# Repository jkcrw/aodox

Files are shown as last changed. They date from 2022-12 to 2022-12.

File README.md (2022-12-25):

# AODox
Fully custom mechanical keyboard optimized for speed/ergonomics. Supports standard Qwerty and Qwerty-like key layouts as well as [Sparrowhawk steno](https://github.com/jxcrw/sphk). Powered by [QMK Firmware](https://github.com/qmk/qmk_firmware).

More documentation coming when time allows.

<p align="center">
  
</p>

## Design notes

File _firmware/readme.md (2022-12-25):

# AODox

AODox

A short description of the keyboard/project

* Keyboard Maintainer: [jxcrw](https://github.com/yourusername)
* Hardware Supported: The PCBs, controllers supported
* Hardware Availability: Links to where you can find this hardware

Make example for this keyboard (after setting up your build environment):

    make aodox:default

See the [build environment setup](https://docs.qmk.fm/#/getting_started_build_tools) and the [make instructions](https://docs.qmk.fm/#/getting_started_make_guide) for more information. Brand new to QMK? Start with our [Complete Newbs Guide](https://docs.qmk.fm/#/newbs).

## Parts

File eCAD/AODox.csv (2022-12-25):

Reference | Value | Footprint | Datasheet
U1 | ATMEGA32U4 | Package_QFP:TQFP-44_10x10mm_P0.8mm
J2 | USB C Port | Connector_USB:USB_C_Receptacle_GCT_USB4085 | https://www.usb.org/sites/default/files/documents/usb_type-c.zip
C7 | 22p | Capacitor_SMD:C_0805_2012Metric_Pad1.15x1.40mm_HandSolder | ~
C6 | 22p | Capacitor_SMD:C_0805_2012Metric_Pad1.15x1.40mm_HandSolder | ~
C1 | 0.1u | Capacitor_SMD:C_0805_2012Metric_Pad1.15x1.40mm_HandSolder | ~
C2 | 0.1u | Capacitor_SMD:C_0805_2012Metric_Pad1.15x1.40mm_HandSolder | ~
C3 | 0.1u | Capacitor_SMD:C_0805_2012Metric_Pad1.15x1.40mm_HandSolder | ~
C4 | 0.1u | Capacitor_SMD:C_0805_2012Metric_Pad1.15x1.40mm_HandSolder | ~
C5 | 4.7u | Capacitor_SMD:C_0805_2012Metric_Pad1.15x1.40mm_HandSolder | ~
SW1 | SW_Push | Button_Switch_SMD:SW_SPST_CK_KXT3 | ~
R1 | 10k | Resistor_SMD:R_0805_2012Metric_Pad1.15x1.40mm_HandSolder | ~
R4 | 10k | Resistor_SMD:R_0805_2012Metric_Pad1.15x1.40mm_HandSolder | ~
R5 | 5.1k | Resistor_SMD:R_0805_2012Metric_Pad1.15x1.40mm_HandSolder | ~
R6 | 5.1k | Resistor_SMD:R_0805_2012Metric_Pad1.15x1.40mm_HandSolder | ~
R2 | 22 | Resistor_SMD:R_0805_2012Metric_Pad1.15x1.40mm_HandSolder | ~
R3 | 22 | Resistor_SMD:R_0805_2012Metric_Pad1.15x1.40mm_HandSolder | ~
C8 | 1u | Capacitor_SMD:C_0805_2012Metric_Pad1.15x1.40mm_HandSolder | ~
J1 | MCU Prog | Connector_PinHeader_2.54mm:PinHeader_1x06_P2.54mm_Vertical | ~
Y1 | XTAL_18p | Crystal:Crystal_SMD_SeikoEpson_FA238-4Pin_3.2x2.5mm_HandSoldering | ~
K0:1 | KEYSW | keyboard_parts_AO:Kailh_socket
D0:1 | D_Small_ALT | Diode_SMD:D_SOD-323_HandSoldering | ~
K1:1 | KEYSW | keyboard_parts_AO:Kailh_socket
D1:1 | D_Small_ALT | Diode_SMD:D_SOD-323_HandSoldering | ~
K2:1 | KEYSW | keyboard_parts_AO:Kailh_socket
D2:1 | D_Small_ALT | Diode_SMD:D_SOD-323_HandSoldering | ~
K3:1 | KEYSW | keyboard_parts_AO:Kailh_socket
D3:1 | D_Small_ALT | Diode_SMD:D_SOD-323_HandSoldering | ~
K4:1 | KEYSW | keyboard_parts_AO:Kailh_socket
D4:1 | D_Small_ALT | Diode_SMD:D_SOD-323_HandSoldering | ~
K0:2 | KEYSW | keyboard_parts_AO:Kailh_socket
D0:2 | D_Small_ALT | Diode_SMD:D_SOD-323_HandSoldering | ~
K1:2 | KEYSW | keyboard_parts_AO:Kailh_socket
D1:2 | D_Small_ALT | Diode_SMD:D_SOD-323_HandSoldering | ~
K2:2 | KEYSW | keyboard_parts_AO:Kailh_socket
D2:2 | D_Small_ALT | Diode_SMD:D_SOD-323_HandSoldering | ~
K3:2 | KEYSW | keyboard_parts_AO:Kailh_socket
D3:2 | D_Small_ALT | Diode_SMD:D_SOD-323_HandSoldering | ~
K4:2 | KEYSW | keyboard_parts_AO:Kailh_socket
D4:2 | D_Small_ALT | Diode_SMD:D_SOD-323_HandSoldering | ~
K0:3 | KEYSW | keyboard_parts_AO:Kailh_socket
D0:3 | D_Small_ALT | Diode_SMD:D_SOD-323_HandSoldering | ~
K1:3 | KEYSW | keyboard_parts_AO:Kailh_socket
D1:3 | D_Small_ALT | Diode_SMD:D_SOD-323_HandSoldering | ~
K2:3 | KEYSW | keyboard_parts_AO:Kailh_socket
D2:3 | D_Small_ALT | Diode_SMD:D_SOD-323_HandSoldering | ~
K3:3 | KEYSW | keyboard_parts_AO:Kailh_socket
D3:3 | D_Small_ALT | Diode_SMD:D_SOD-323_HandSoldering | ~
K4:3 | KEYSW | keyboard_parts_AO:Kailh_socket
D4:3 | D_Small_ALT | Diode_SMD:D_SOD-323_HandSoldering | ~
K0:4 | KEYSW | keyboard_parts_AO:Kailh_socket
D0:4 | D_Small_ALT | Diode_SMD:D_SOD-323_HandSoldering | ~
K1:4 | KEYSW | keyboard_parts_AO:Kailh_socket
D1:4 | D_Small_ALT | Diode_SMD:D_SOD-323_HandSoldering | ~
K2:4 | KEYSW | keyboard_parts_AO:Kailh_socket
D2:4 | D_Small_ALT | Diode_SMD:D_SOD-323_HandSoldering | ~
K3:4 | KEYSW | keyboard_parts_AO:Kailh_socket
D3:4 | D_Small_ALT | Diode_SMD:D_SOD-323_HandSoldering | ~
K4:4 | KEYSW | keyboard_parts_AO:Kailh_socket
D4:4 | D_Small_ALT | Diode_SMD:D_SOD-323_HandSoldering | ~
K0:5 | KEYSW | keyboard_parts_AO:Kailh_socket
D0:5 | D_Small_ALT | Diode_SMD:D_SOD-323_HandSoldering | ~
K1:5 | KEYSW | keyboard_parts_AO:Kailh_socket
D1:5 | D_Small_ALT | Diode_SMD:D_SOD-323_HandSoldering | ~
K2:5 | KEYSW | keyboard_parts_AO:Kailh_socket
D2:5 | D_Small_ALT | Diode_SMD:D_SOD-323_HandSoldering | ~
K3:5 | KEYSW | keyboard_parts_AO:Kailh_socket
D3:5 | D_Small_ALT | Diode_SMD:D_SOD-323_HandSoldering | ~
K4:5 | KEYSW | keyboard_parts_AO:Kailh_socket
D4:5 | D_Small_ALT | Diode_SMD:D_SOD-323_HandSoldering | ~
K0:6 | KEYSW | keyboard_parts_AO:Kailh_socket
D0:6 | D_Small_ALT | Diode_SMD:D_SOD-323_HandSoldering | ~
K1:6 | KEYSW | keyboard_parts_AO:Kailh_socket
D1:6 | D_Small_ALT | Diode_SMD:D_SOD-323_HandSoldering | ~
K2:6 | KEYSW | keyboard_parts_AO:Kailh_socket
D2:6 | D_Small_ALT | Diode_SMD:D_SOD-323_HandSoldering | ~
K4:6 | KEYSW | keyboard_parts_AO:Kailh_socket
D4:6 | D_Small_ALT | Diode_SMD:D_SOD-323_HandSoldering | ~
K4:7 | KEYSW | keyboard_parts_AO:Kailh_socket
D4:7 | D_Small_ALT | Diode_SMD:D_SOD-323_HandSoldering | ~
K3:7 | KEYSW | keyboard_parts_AO:Kailh_socket
D3:7 | D_Small_ALT | Diode_SMD:D_SOD-323_HandSoldering | ~
D4:0 | D_Small_ALT | Diode_SMD:D_SOD-323_HandSoldering | ~
K4:0 | KEYSW | keyboard_parts_AO:Kailh_socket
D3:0 | D_Small_ALT | Diode_SMD:D_SOD-323_HandSoldering | ~
K3:0 | KEYSW | keyboard_parts_AO:Kailh_socket
D2:0 | D_Small_ALT | Diode_SMD:D_SOD-323_HandSoldering | ~
K2:0 | KEYSW | keyboard_parts_AO:Kailh_socket
D1:0 | D_Small_ALT | Diode_SMD:D_SOD-323_HandSoldering | ~
K1:0 | KEYSW | keyboard_parts_AO:Kailh_socket
D0:0 | D_Small_ALT | Diode_SMD:D_SOD-323_HandSoldering | ~
K0:0 | KEYSW | keyboard_parts_AO:Kailh_socket
K1:8 | KEYSW | keyboard_parts_AO:Kailh_socket
D1:8 | D_Small_ALT | Diode_SMD:D_SOD-323_HandSoldering | ~
K2:8 | KEYSW | keyboard_parts_AO:Kailh_socket
D2:8 | D_Small_ALT | Diode_SMD:D_SOD-323_HandSoldering | ~
K4:9 | KEYSW | keyboard_parts_AO:Kailh_socket
D4:9 | D_Small_ALT | Diode_SMD:D_SOD-323_HandSoldering | ~
K3:9 | KEYSW | keyboard_parts_AO:Kailh_socket
D3:9 | D_Small_ALT | Diode_SMD:D_SOD-323_HandSoldering | ~
K0:10 | KEYSW | keyboard_parts_AO:Kailh_socket
D0:10 | D_Small_ALT | Diode_SMD:D_SOD-323_HandSoldering | ~
K1:10 | KEYSW | keyboard_parts_AO:Kailh_socket
D1:10 | D_Small_ALT | Diode_SMD:D_SOD-323_HandSoldering | ~
K2:10 | KEYSW | keyboard_parts_AO:Kailh_socket
D2:10 | D_Small_ALT | Diode_SMD:D_SOD-323_HandSoldering | ~
K4:10 | KEYSW | keyboard_parts_AO:Kailh_socket
D4:10 | D_Small_ALT | Diode_SMD:D_SOD-323_HandSoldering | ~
K0:12 | KEYSW | keyboard_parts_AO:Kailh_socket
D0:12 | D_Small_ALT | Diode_SMD:D_SOD-323_HandSoldering | ~
K1:12 | KEYSW | keyboard_parts_AO:Kailh_socket
D1:12 | D_Small_ALT | Diode_SMD:D_SOD-323_HandSoldering | ~
K2:12 | KEYSW | keyboard_parts_AO:Kailh_socket
D2:12 | D_Small_ALT | Diode_SMD:D_SOD-323_HandSoldering | ~
K3:12 | KEYSW | keyboard_parts_AO:Kailh_socket
D3:12 | D_Small_ALT | Diode_SMD:D_SOD-323_HandSoldering | ~
K4:12 | KEYSW | keyboard_parts_AO:Kailh_socket
D4:12 | D_Small_ALT | Diode_SMD:D_SOD-323_HandSoldering | ~
K0:13 | KEYSW | keyboard_parts_AO:Kailh_socket
D0:13 | D_Small_ALT | Diode_SMD:D_SOD-323_HandSoldering | ~
K1:13 | KEYSW | keyboard_parts_AO:Kailh_socket
D1:13 | D_Small_ALT | Diode_SMD:D_SOD-323_HandSoldering | ~
K2:13 | KEYSW | keyboard_parts_AO:Kailh_socket
D2:13 | D_Small_ALT | Diode_SMD:D_SOD-323_HandSoldering | ~
K3:13 | KEYSW | keyboard_parts_AO:Kailh_socket
D3:13 | D_Small_ALT | Diode_SMD:D_SOD-323_HandSoldering | ~
K4:13 | KEYSW | keyboard_parts_AO:Kailh_socket
D4:13 | D_Small_ALT | Diode_SMD:D_SOD-323_HandSoldering | ~
K0:14 | KEYSW | keyboard_parts_AO:Kailh_socket
D0:14 | D_Small_ALT | Diode_SMD:D_SOD-323_HandSoldering | ~
K1:14 | KEYSW | keyboard_parts_AO:Kailh_socket
D1:14 | D_Small_ALT | Diode_SMD:D_SOD-323_HandSoldering | ~
K2:14 | KEYSW | keyboard_parts_AO:Kailh_socket
D2:14 | D_Small_ALT | Diode_SMD:D_SOD-323_HandSoldering | ~
K3:14 | KEYSW | keyboard_parts_AO:Kailh_socket
D3:14 | D_Small_ALT | Diode_SMD:D_SOD-323_HandSoldering | ~
K4:14 | KEYSW | keyboard_parts_AO:Kailh_socket
D4:14 | D_Small_ALT | Diode_SMD:D_SOD-323_HandSoldering | ~
K0:15 | KEYSW | keyboard_parts_AO:Kailh_socket
D0:15 | D_Small_ALT | Diode_SMD:D_SOD-323_HandSoldering | ~
K1:15 | KEYSW | keyboard_parts_AO:Kailh_socket
D1:15 | D_Small_ALT | Diode_SMD:D_SOD-323_HandSoldering | ~
K2:15 | KEYSW | keyboard_parts_AO:Kailh_socket
D2:15 | D_Small_ALT | Diode_SMD:D_SOD-323_HandSoldering | ~
K3:15 | KEYSW | keyboard_parts_AO:Kailh_socket
D3:15 | D_Small_ALT | Diode_SMD:D_SOD-323_HandSoldering | ~
K4:15 | KEYSW | keyboard_parts_AO:Kailh_socket
D4:15 | D_Small_ALT | Diode_SMD:D_SOD-323_HandSoldering | ~
K0:16 | KEYSW | keyboard_parts_AO:Kailh_socket
D0:16 | D_Small_ALT | Diode_SMD:D_SOD-323_HandSoldering | ~
K1:16 | KEYSW | keyboard_parts_AO:Kailh_socket
D1:16 | D_Small_ALT | Diode_SMD:D_SOD-323_HandSoldering | ~
K2:16 | KEYSW | keyboard_parts_AO:Kailh_socket
D2:16 | D_Small_ALT | Diode_SMD:D_SOD-323_HandSoldering | ~
K3:16 | KEYSW | keyboard_parts_AO:Kailh_socket
D3:16 | D_Small_ALT | Diode_SMD:D_SOD-323_HandSoldering | ~
K4:16 | KEYSW | keyboard_parts_AO:Kailh_socket
D4:16 | D_Small_ALT | Diode_SMD:D_SOD-323_HandSoldering | ~
D4:11 | D_Small_ALT | Diode_SMD:D_SOD-323_HandSoldering | ~
K4:11 | KEYSW | keyboard_parts_AO:Kailh_socket
D3:11 | D_Small_ALT | Diode_SMD:D_SOD-323_HandSoldering | ~
K3:11 | KEYSW | keyboard_parts_AO:Kailh_socket
D2:11 | D_Small_ALT | Diode_SMD:D_SOD-323_HandSoldering | ~
K2:11 | KEYSW | keyboard_parts_AO:Kailh_socket
D1:11 | D_Small_ALT | Diode_SMD:D_SOD-323_HandSoldering | ~
K1:11 | KEYSW | keyboard_parts_AO:Kailh_socket
D0:11 | D_Small_ALT | Diode_SMD:D_SOD-323_HandSoldering | ~
K0:11 | KEYSW | keyboard_parts_AO:Kailh_socket

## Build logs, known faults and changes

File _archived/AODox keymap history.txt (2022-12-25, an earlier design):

commit da2d01808503ddcafd8279fb72374b3331a3387b
Merge: 33126c9246 ae34dde677
Author: Jak Crow <jak@jxcrw.io>
Date:   Sat Dec 11 19:10:52 2021 -0800

    Merge branch 'master' of https://github.com/qmk/qmk_firmware

commit 33126c92460ebc105c9933ecef562ca10e2ec47d
Author: Jak Crow <jak@jxcrw.io>
Date:   Sat Dec 11 17:25:13 2021 -0800

    Commit before pulling from origin

diff --git a/keyboards/aodox/keymaps/default/keymap.c b/keyboards/aodox/keymaps/default/keymap.c
index 64bbab2256..fd905350bf 100644
--- a/keyboards/aodox/keymaps/default/keymap.c
+++ b/keyboards/aodox/keymaps/default/keymap.c
@@ -35,7 +35,7 @@ enum custom_keycodes {
 const uint16_t PROGMEM keymaps[][MATRIX_ROWS][MATRIX_COLS] = {
 /*Steno
  * ┌───────┬─────┬─────┬─────┬─────┬─────┬─────┐             ┌─────┬─────┬─────┬─────┬─────┬─────┬───────┐
- * │   -   │ F1  │ F2  │ F3  │ F4  │ F5  │tQWTY│ Center keys │ F13 │  F6 │  F7 │  F8 │  F9 │ F10 │   ~   │
+ * │   -   │ F1  │ F2  │ F3  │ F4  │ F5  │     │ Center keys │ F13 │  F6 │  F7 │  F8 │  F9 │ F10 │   ~   │
  * ├───────┼─────┼─────┼─────┼─────┼─────┼─────┤   ┌─────┐   ├─────┼─────┼─────┼─────┼─────┼─────┼───────┤
  * │Ent/MDA│  Q  │  W  │  E  │  R  │  T  │ F14 │   │tQWTY│   │     │  Y  │  U  │  I  │  O  │  P  │  F22  │
  * ├───────┼─────┼─────┼─────╆─────╅─────┤     │   ├─────┤   │     ├─────╆─────╅─────┼─────┼─────┼───────┤
@@ -50,7 +50,7 @@ const uint16_t PROGMEM keymaps[][MATRIX_ROWS][MATRIX_COLS] = {
  */
 [STNO] = LAYOUT(
     // Left hand
-    KC_MINS,              KC_F1,          KC_F2,         KC_F3,     KC_F4,  KC_F5,  TG(QWTY),
+    KC_MINS,              KC_F1,          KC_F2,         KC_F3,     KC_F4,  KC_F5,  KC_NO,
     LT(MDIA, KC_ENT),     KC_Q,           KC_W,          KC_E,      KC_R,   KC_T,   KC_F14,
     LT(SNPD, KC_TAB),     KC_A,           KC_S,          KC_D,      KC_F,   KC_G,
     KC_F15,               KC_Z,           KC_X,          KC_C,      KC_V,   KC_B,   LCAG_T(KC_ESC), KC_PGUP,
@@ -74,7 +74,7 @@ const uint16_t PROGMEM keymaps[][MATRIX_ROWS][MATRIX_COLS] = {
  * ├───────┼─────┼─────┼─────┼─────┼─────┼─────┤   ┌─────┐   ├─────┼─────┼─────┼─────┼─────┼─────┼───────┤
  * │       │     │     │     │     │     │     │   │     │   │ CALC│  :  │  7  │  8  │  9  │  *  │   \   │
  * ├───────┼─────┼─────┼─────╆─────╅─────┤     │   ├─────┤   │     ├─────╆─────╅─────┼─────┼─────┼───────┤
- * │       │     │     │     │     │     ├─────┤   │     │   ├─────┤  .  │  4  │  5  │  6  │  +  │   -   │
+ * │       │     │     │     │     │     ├─────┤   │     │   ├─────┤  .  │  4  │  5  │  6  │  -  │   +   │
  * ├───────┼─────┼─────┼─────╄─────╃─────┤     │   └─────┘   │     ├─────╄─────╃─────┼─────┼─────┼───────┤
  * │       │     │     │     │     │     │     ├─────┐ ┌─────┤     │  ,  │  1  │  2  │  3  │  /  │       │
  * └┬──────┼─────┼─────┼─────┼─────┼─────┼─────┤     │ │     ├─────┼─────┼─────┼─────┼─────┼─────┼──────┬┘
@@ -98,7 +98,7 @@ const uint16_t PROGMEM keymaps[][MATRIX_ROWS][MATRIX_COLS] = {
     // Right hand
              KC_NLCK, KC_TRNS, KC_TRNS, KC_TRNS, KC_TRNS, KC_F11,  KC_F12,
              KC_CALC, KC_COLN,  KC_7,    KC_8,    KC_9,   KC_PAST, KC_BSLS,
-                      KC_PDOT,  KC_4,    KC_5,    KC_6,   KC_PPLS, KC_PMNS,
+                      KC_PDOT,  KC_4,    KC_5,    KC_6,   KC_PMNS, KC_PPLS,
     KC_TRNS, KC_TRNS, KC_TRNS,  KC_1,    KC_2,    KC_3,   KC_TRNS, KC_TRNS,
     KC_TRNS, KC_TRNS, KC_TRNS,  KC_0,   KC_TRNS, KC_TRNS, KC_TRNS, KC_TRNS
 ),
@@ -183,8 +183,8 @@ const uint16_t PROGMEM keymaps[][MATRIX_ROWS][MATRIX_COLS] = {
  * ├───────┼─────┼─────┼─────╄─────╃─────┤     │   └─────┘   │     ├─────╄─────╃─────┼─────┼─────┼───────┤
  * │       │     │     │     │Mute │     │     ├─────┐ ┌─────┤     │     │     │     │     │     │       │
  * └┬──────┼─────┼─────┼─────┼─────┼─────┼─────┤     │ │     ├─────┼─────┼─────┼─────┼─────┼─────┼──────┬┘
- *  │      │     │     │     │Play/│     │     ├─────┤ ├─────┤     │     │     │     │     │     │      │
- *  └──────┴─────┴─────┴─────┤Pause│     │     │     │ │QMKVN│     │     │     ├─────┴─────┴─────┴──────┘
+ *  │      │     │     │     │     │Play/│     ├─────┤ ├─────┤     │     │     │     │     │     │      │
+ *  └──────┴─────┴─────┴─────┤     │Pause│     │     │ │QMKVN│     │     │     ├─────┴─────┴─────┴──────┘
  *                           └─────┴─────┴─────┴─────┘ └─────┴─────┴─────┴─────┘
                   Left hand                                                     Right hand
  */

commit 1bd1c5d338674708817bb1abb0dcf430e1dbd5ef
Merge: 50fa298e64 d99806cc27
Author: Jak Crow <jak@jxcrw.io>
Date:   Mon Mar 15 23:06:30 2021 -0600

    Merge branch 'master' of https://github.com/qmk/qmk_firmware

commit 50fa298e64d3b0f0613dfca3f9435bffdd475358
Author: Jak Crow <jak@jxcrw.io>
Date:   Mon Mar 15 22:57:07 2021 -0600

    Commit before pulling from origin

diff --git a/keyboards/aodox/keymaps/default/keymap.c b/keyboards/aodox/keymaps/default/keymap.c
index b41064e9db..64bbab2256 100644
--- a/keyboards/aodox/keymaps/default/keymap.c
+++ b/keyboards/aodox/keymaps/default/keymap.c
@@ -33,7 +33,7 @@ enum custom_keycodes {
 };
 
 const uint16_t PROGMEM keymaps[][MATRIX_ROWS][MATRIX_COLS] = {
-/* Steno
+/*Steno
  * ┌───────┬─────┬─────┬─────┬─────┬─────┬─────┐             ┌─────┬─────┬─────┬─────┬─────┬─────┬───────┐
  * │   -   │ F1  │ F2  │ F3  │ F4  │ F5  │tQWTY│ Center keys │ F13 │  F6 │  F7 │  F8 │  F9 │ F10 │   ~   │
  * ├───────┼─────┼─────┼─────┼─────┼─────┼─────┤   ┌─────┐   ├─────┼─────┼─────┼─────┼─────┼─────┼───────┤

commit 1def5623de13e924e3192fbd599524c30b964cb6
Author: Jak Crow <jak@jxcrw.io>
Date:   Mon Mar 8 15:43:43 2021 -0700

    Fix issue where custom keycodes overwrote KC_NO
    
    Same issue described here: https://github.com/qmk/qmk_firmware/issues/1315.

diff --git a/keyboards/aodox/keymaps/default/keymap.c b/keyboards/aodox/keymaps/default/keymap.c
index 692f5f3661..b41064e9db 100644
--- a/keyboards/aodox/keymaps/default/keymap.c
+++ b/keyboards/aodox/keymaps/default/keymap.c
@@ -27,8 +27,8 @@ enum AODox_layers {
 
 // Defines the keycodes used by our macros in process_record_user
 enum custom_keycodes {
-    QMK_VRN,
-    QMKBEST = SAFE_RANGE,
+    QMK_VRN = SAFE_RANGE,
+    QMKBEST,
     QMKURL
 };

commit c51e20164d6fc8d213324356e29feac960facb4e
Author: Jak Crow <jak@jxcrw.io>
Date:   Sun Jan 24 03:22:54 2021 -0700

    Minor fixups after uncaught merge conflicts

diff --git a/keyboards/aodox/config.h b/keyboards/aodox/config.h
index b9f22d032c..2dfcb97acd 100644
--- a/keyboards/aodox/config.h
+++ b/keyboards/aodox/config.h
@@ -23,14 +23,9 @@ along with this program.  If not, see <http://www.gnu.org/licenses/>.
 #define VENDOR_ID 0xFEED
 #define PRODUCT_ID 0x6060
 #define DEVICE_VER 0x0001
-<<<<<<< HEAD:keyboards/aodox/config.h
 #define MANUFACTURER AOindustries
 #define PRODUCT AODox
 #define DESCRIPTION Ergonomic mech optimized for steno
-=======
-#define MANUFACTURER Kai Eckert
-#define PRODUCT Rabbit68
->>>>>>> 944cf6476e1a8ddfab7c08dbe4cc1fee3ea4beb7:keyboards/rabbit/rabbit68/config.h
 
 /* key matrix size */
 #define MATRIX_ROWS 5
diff --git a/keyboards/aodox/keymaps/default/keymap.c b/keyboards/aodox/keymaps/default/keymap.c
index 9a36579b46..692f5f3661 100644
--- a/keyboards/aodox/keymaps/default/keymap.c
+++ b/keyboards/aodox/keymaps/default/keymap.c
@@ -39,7 +39,7 @@ const uint16_t PROGMEM keymaps[][MATRIX_ROWS][MATRIX_COLS] = {
  * ├───────┼─────┼─────┼─────┼─────┼─────┼─────┤   ┌─────┐   ├─────┼─────┼─────┼─────┼─────┼─────┼───────┤
  * │Ent/MDA│  Q  │  W  │  E  │  R  │  T  │ F14 │   │tQWTY│   │     │  Y  │  U  │  I  │  O  │  P  │  F22  │
  * ├───────┼─────┼─────┼─────╆─────╅─────┤     │   ├─────┤   │     ├─────╆─────╅─────┼─────┼─────┼───────┤
- * │Tab/SYM│  A  │  S  │  D  │  F  │  G  ├─────┤   │tQWTY│   ├─────┤  H  │  ←  │  ↓  │  ↑  │  →  │   "   │
+ * │Tab/SYM│  A  │  S  │  D  │  F  │  G  ├─────┤   │ Esc │   ├─────┤  H  │  ←  │  ↓  │  ↑  │  →  │   "   │
  * ├───────┼─────┼─────┼─────╄─────╃─────┤Esc/ │   └─────┘   │  K/ ├─────╄─────╃─────┼─────┼─────┼───────┤
  * │  F15  │  Z  │  X  │  C  │  V  │  B  │LCAG ├─────┐ ┌─────┤ LCAG│  N  │  M  │  ,  │  .  │  ?  │  F23  │
  * └┬──────┼─────┼─────┼─────┼─────┼─────┼─────┤PgUp │ │ PgDn├─────┼─────┼─────┼─────┼─────┼─────┼──────┬┘
diff --git a/keyboards/aodox/rules.mk b/keyboards/aodox/rules.mk
index 6c1141c771..35be9ca64c 100644
--- a/keyboards/aodox/rules.mk
+++ b/keyboards/aodox/rules.mk
@@ -39,9 +39,4 @@ MIDI_ENABLE = no            # MIDI support
 BLUETOOTH_ENABLE = no       # Enable Bluetooth with the Adafruit EZ-Key HID
 AUDIO_ENABLE = no           # Audio output on port C6
 FAUXCLICKY_ENABLE = no      # Use buzzer to emulate clicky switches
-<<<<<<< HEAD:keyboards/aodox/rules.mk
 HD44780_ENABLE = no         # Enable support for HD44780 based LCDs
-=======
-
-LAYOUTS = tkl_ansi
->>>>>>> 944cf6476e1a8ddfab7c08dbe4cc1fee3ea4beb7:keyboards/yurei/rules.mk

commit 7c6b00067a2d815d4e643c5a8e4a8ca4160bc8eb
Merge: 84a1318af8 944cf6476e
Author: Jak Crow <jak@jxcrw.io>
Date:   Sun Jan 24 03:09:02 2021 -0700

    Merge branch 'master' of https://github.com/qmk/qmk_firmware

commit 84a1318af8c1b8b18dae2eb452bca19686189983
Author: Jak Crow <jak@jxcrw.io>
Date:   Sun Jan 24 03:05:37 2021 -0700

    Commit before pulling from origin

diff --git a/keyboards/aodox/keymaps/default/keymap.c b/keyboards/aodox/keymaps/default/keymap.c
index 554c06eecb..9a36579b46 100644
--- a/keyboards/aodox/keymaps/default/keymap.c
+++ b/keyboards/aodox/keymaps/default/keymap.c
@@ -58,7 +58,7 @@ const uint16_t PROGMEM keymaps[][MATRIX_ROWS][MATRIX_COLS] = {
 
     // Center keys
     TG(QWTY),
-    TG(QWTY),
+    KC_ESC,
 
     // Right hand
                       KC_F13,    KC_F6,   KC_F7,    KC_F8,         KC_F9,          KC_F10,     KC_GRV,

commit 70cf6908af536ed6b435785d5623e3d0909652d5
Author: Jak Crow <jak@jxcrw.io>
Date:   Mon Nov 23 03:36:48 2020 -0700

    Finish adding QMK_VRN key

diff --git a/keyboards/aodox/keymaps/default/keymap.c b/keyboards/aodox/keymaps/default/keymap.c
index 1c6a07425b..554c06eecb 100644
--- a/keyboards/aodox/keymaps/default/keymap.c
+++ b/keyboards/aodox/keymaps/default/keymap.c
@@ -14,6 +14,7 @@
  * along with this program.  If not, see <http://www.gnu.org/licenses/>.
  */
 #include QMK_KEYBOARD_H
+#include "version.h"
 
 // Defines names for use in layer keycodes and the keymap
 enum AODox_layers {
@@ -26,6 +27,7 @@ enum AODox_layers {
 
 // Defines the keycodes used by our macros in process_record_user
 enum custom_keycodes {
+    QMK_VRN,
     QMKBEST = SAFE_RANGE,
     QMKURL
 };
@@ -244,6 +246,12 @@ const uint16_t PROGMEM keymaps[][MATRIX_ROWS][MATRIX_COLS] = {
 
 bool process_record_user(uint16_t keycode, keyrecord_t *record) {
     switch (keycode) {
+        case QMK_VRN:
+            if (record->event.pressed) {
+                SEND_STRING(QMK_KEYBOARD "/" QMK_KEYMAP " @ " QMK_VERSION);
+            } else {
+            }
+            break;
         case QMKBEST:
             if (record->event.pressed) {
                 // when keycode QMKBEST is pressed

commit c72bdc5cdfe485e60ed7036b082f4726a7ba58ac
Author: Jak Crow <jak@jxcrw.io>
Date:   Mon Nov 23 03:15:44 2020 -0700

    Add QMK_VRN key

diff --git a/keyboards/aodox/keymaps/default/keymap.c b/keyboards/aodox/keymaps/default/keymap.c
index e6b660f04f..1c6a07425b 100644
--- a/keyboards/aodox/keymaps/default/keymap.c
+++ b/keyboards/aodox/keymaps/default/keymap.c
@@ -33,11 +33,11 @@ enum custom_keycodes {
 const uint16_t PROGMEM keymaps[][MATRIX_ROWS][MATRIX_COLS] = {
 /* Steno
  * ┌───────┬─────┬─────┬─────┬─────┬─────┬─────┐             ┌─────┬─────┬─────┬─────┬─────┬─────┬───────┐
- * │   -   │ F1  │ F2  │ F3  │ F4  │ F5  │QWTY │ Center keys │ F13 │  F6 │  F7 │  F8 │  F9 │ F10 │   ~   │
+ * │   -   │ F1  │ F2  │ F3  │ F4  │ F5  │tQWTY│ Center keys │ F13 │  F6 │  F7 │  F8 │  F9 │ F10 │   ~   │
  * ├───────┼─────┼─────┼─────┼─────┼─────┼─────┤   ┌─────┐   ├─────┼─────┼─────┼─────┼─────┼─────┼───────┤
- * │Ent/MDA│  Q  │  W  │  E  │  R  │  T  │ F14 │   │     │   │     │  Y  │  U  │  I  │  O  │  P  │  F22  │
+ * │Ent/MDA│  Q  │  W  │  E  │  R  │  T  │ F14 │   │tQWTY│   │     │  Y  │  U  │  I  │  O  │  P  │  F22  │
  * ├───────┼─────┼─────┼─────╆─────╅─────┤     │   ├─────┤   │     ├─────╆─────╅─────┼─────┼─────┼───────┤
- * │Tab/SYM│  A  │  S  │  D  │  F  │  G  ├─────┤   │     │   ├─────┤  H  │  ←  │  ↓  │  ↑  │  →  │   "   │
+ * │Tab/SYM│  A  │  S  │  D  │  F  │  G  ├─────┤   │tQWTY│   ├─────┤  H  │  ←  │  ↓  │  ↑  │  →  │   "   │
  * ├───────┼─────┼─────┼─────╄─────╃─────┤Esc/ │   └─────┘   │  K/ ├─────╄─────╃─────┼─────┼─────┼───────┤
  * │  F15  │  Z  │  X  │  C  │  V  │  B  │LCAG ├─────┐ ┌─────┤ LCAG│  N  │  M  │  ,  │  .  │  ?  │  F23  │
  * └┬──────┼─────┼─────┼─────┼─────┼─────┼─────┤PgUp │ │ PgDn├─────┼─────┼─────┼─────┼─────┼─────┼──────┬┘
@@ -56,7 +56,7 @@ const uint16_t PROGMEM keymaps[][MATRIX_ROWS][MATRIX_COLS] = {
 
     // Center keys
     TG(QWTY),
-    KC_TRNS,
+    TG(QWTY),
 
     // Right hand
                       KC_F13,    KC_F6,   KC_F7,    KC_F8,         KC_F9,          KC_F10,     KC_GRV,
@@ -182,7 +182,7 @@ const uint16_t PROGMEM keymaps[][MATRIX_ROWS][MATRIX_COLS] = {
  * │       │     │     │     │Mute │     │     ├─────┐ ┌─────┤     │     │     │     │     │     │       │
  * └┬──────┼─────┼─────┼─────┼─────┼─────┼─────┤     │ │     ├─────┼─────┼─────┼─────┼─────┼─────┼──────┬┘
  *  │      │     │     │     │Play/│     │     ├─────┤ ├─────┤     │     │     │     │     │     │      │
- *  └──────┴─────┴─────┴─────┤Pause│     │     │     │ │     │     │     │     ├─────┴─────┴─────┴──────┘
+ *  └──────┴─────┴─────┴─────┤Pause│     │     │     │ │QMKVN│     │     │     ├─────┴─────┴─────┴──────┘
  *                           └─────┴─────┴─────┴─────┘ └─────┴─────┴─────┴─────┘
                   Left hand                                                     Right hand
  */
@@ -203,7 +203,7 @@ const uint16_t PROGMEM keymaps[][MATRIX_ROWS][MATRIX_COLS] = {
              KC_TRNS, KC_TRNS, KC_TRNS, KC_TRNS, KC_TRNS, KC_TRNS, KC_TRNS,
                       KC_TRNS, KC_TRNS, KC_TRNS, KC_TRNS, KC_TRNS, KC_PWR,
     KC_TRNS, KC_TRNS, KC_TRNS, KC_TRNS, KC_TRNS, KC_TRNS, KC_TRNS, KC_TRNS,
-    KC_TRNS, KC_TRNS, KC_TRNS, KC_TRNS, KC_TRNS, KC_TRNS, KC_TRNS, KC_TRNS
+    QMK_VRN, KC_TRNS, KC_TRNS, KC_TRNS, KC_TRNS, KC_TRNS, KC_TRNS, KC_TRNS
 ),
 
 /* Blank layer

commit f26ba310ee56f86e231c81d75eb285de5d0603e2
Author: Jak Crow <jak@jxcrw.io>
Date:   Sat Oct 17 19:50:11 2020 -0600

    Commit before pulling in from origin 3

diff --git a/keyboards/aodox/keymaps/default/keymap.c b/keyboards/aodox/keymaps/default/keymap.c
index 00346e0278..e6b660f04f 100644
--- a/keyboards/aodox/keymaps/default/keymap.c
+++ b/keyboards/aodox/keymaps/default/keymap.c
@@ -31,7 +31,7 @@ enum custom_keycodes {
 };
 
 const uint16_t PROGMEM keymaps[][MATRIX_ROWS][MATRIX_COLS] = {
-/*Steno
+/* Steno
  * ┌───────┬─────┬─────┬─────┬─────┬─────┬─────┐             ┌─────┬─────┬─────┬─────┬─────┬─────┬───────┐
  * │   -   │ F1  │ F2  │ F3  │ F4  │ F5  │QWTY │ Center keys │ F13 │  F6 │  F7 │  F8 │  F9 │ F10 │   ~   │
  * ├───────┼─────┼─────┼─────┼─────┼─────┼─────┤   ┌─────┐   ├─────┼─────┼─────┼─────┼─────┼─────┼───────┤

commit a1e3489e6a21afd61083b93cacccd6f1deb79512
Author: Jak Crow <jak@jxcrw.io>
Date:   Sat Oct 17 19:48:31 2020 -0600

    Commit before pulling in from origin 2

diff --git a/keyboards/aodox/keymaps/default/keymap.c b/keyboards/aodox/keymaps/default/keymap.c
index e6b660f04f..00346e0278 100644
--- a/keyboards/aodox/keymaps/default/keymap.c
+++ b/keyboards/aodox/keymaps/default/keymap.c
@@ -31,7 +31,7 @@ enum custom_keycodes {
 };
 
 const uint16_t PROGMEM keymaps[][MATRIX_ROWS][MATRIX_COLS] = {
-/* Steno
+/*Steno
  * ┌───────┬─────┬─────┬─────┬─────┬─────┬─────┐             ┌─────┬─────┬─────┬─────┬─────┬─────┬───────┐
  * │   -   │ F1  │ F2  │ F3  │ F4  │ F5  │QWTY │ Center keys │ F13 │  F6 │  F7 │  F8 │  F9 │ F10 │   ~   │
  * ├───────┼─────┼─────┼─────┼─────┼─────┼─────┤   ┌─────┐   ├─────┼─────┼─────┼─────┼─────┼─────┼───────┤

commit 81cfe46e79d15a757441b9420ccb62573844e998
Author: Jak Crow <jak@jxcrw.io>
Date:   Sat Oct 17 19:36:17 2020 -0600

    Commit before pulling in from origin

diff --git a/keyboards/aodox/keymaps/default/keymap.c b/keyboards/aodox/keymaps/default/keymap.c
index 00346e0278..e6b660f04f 100644
--- a/keyboards/aodox/keymaps/default/keymap.c
+++ b/keyboards/aodox/keymaps/default/keymap.c
@@ -31,7 +31,7 @@ enum custom_keycodes {
 };
 
 const uint16_t PROGMEM keymaps[][MATRIX_ROWS][MATRIX_COLS] = {
-/*Steno
+/* Steno
  * ┌───────┬─────┬─────┬─────┬─────┬─────┬─────┐             ┌─────┬─────┬─────┬─────┬─────┬─────┬───────┐
  * │   -   │ F1  │ F2  │ F3  │ F4  │ F5  │QWTY │ Center keys │ F13 │  F6 │  F7 │  F8 │  F9 │ F10 │   ~   │
  * ├───────┼─────┼─────┼─────┼─────┼─────┼─────┤   ┌─────┐   ├─────┼─────┼─────┼─────┼─────┼─────┼───────┤

commit 6e5613d9b37d91255178d547e72446c43bcf8f71
Author: Jak Crow <jak@jxcrw.io>
Date:   Sun Sep 20 02:53:23 2020 -0600

    Change capitalization of AODox keyboard directory

diff --git a/keyboards/aodox/AODox.c b/keyboards/aodox/AODox.c
new file mode 100644
index 0000000000..8c1591b518
--- /dev/null
+++ b/keyboards/aodox/AODox.c
@@ -0,0 +1,50 @@
+/* Copyright 2019 jxcrw
+ *
+ * This program is free software: you can redistribute it and/or modify
+ * it under the terms of the GNU General Public License as published by
+ * the Free Software Foundation, either version 2 of the License, or
+ * (at your option) any later version.
+ *
+ * This program is distributed in the hope that it will be useful,
+ * but WITHOUT ANY WARRANTY; without even the implied warranty of
+ * MERCHANTABILITY or FITNESS FOR A PARTICULAR PURPOSE.  See the
+ * GNU General Public License for more details.
+ *
+ * You should have received a copy of the GNU General Public License
+ * along with this program.  If not, see <http://www.gnu.org/licenses/>.
+ */
+
+#include "AODox.h"
+
+// Optional override functions below.
+// You can leave any or all of these undefined.
+// These are only required if you want to perform custom actions.
+
+/*
+void matrix_init_kb(void) {
+    // put your keyboard start-up code here
+    // runs once when the firmware starts up
+
+    matrix_init_user();
+}
+
+void matrix_scan_kb(void) {
+    // put your looping keyboard code here
+    // runs every cycle (a lot)
+
+    matrix_scan_user();
+}
+
+bool process_record_kb(uint16_t keycode, keyrecord_t *record) {
+    // put your per-action keyboard code here
+    // runs for every action, just before processing by the firmware
+
+    return process_record_user(keycode, record);
+}
+
+bool led_update_kb(led_t led_state) {
+    // put your keyboard LED indicator (ex: Caps Lock LED) toggling code here
+
+    return led_update_user(led_state);
+}
+*/
diff --git a/keyboards/aodox/AODox.h b/keyboards/aodox/AODox.h
new file mode 100644
index 0000000000..499ccd1caa
--- /dev/null
+++ b/keyboards/aodox/AODox.h
@@ -0,0 +1,82 @@
+/* Copyright 2019 Jak Crow
+ *
+ * This program is free software: you can redistribute it and/or modify
+ * it under the terms of the GNU General Public License as published by
+ * the Free Software Foundation, either version 2 of the License, or
+ * (at your option) any later version.
+ *
+ * This program is distributed in the hope that it will be useful,
+ * but WITHOUT ANY WARRANTY; without even the implied warranty of
+ * MERCHANTABILITY or FITNESS FOR A PARTICULAR PURPOSE.  See the
+ * GNU General Public License for more details.
+ *
+ * You should have received a copy of the GNU General Public License
+ * along with this program.  If not, see <http://www.gnu.org/licenses/>.
+ */
+
+#pragma once
+
+#include "quantum.h"
+
+/* This is a shortcut to help you visually see your layout.
+ *
+ * The first section contains all of the arguments representing the physical
+ * layout of the board and position of the keys.
+ *
+ * The second converts the arguments into a two-dimensional array which
+ * represents the switch matrix.
+ */
+
+/* Blank layout
+ * ┌───────┬─────┬─────┬─────┬─────┬─────┬─────┐             ┌─────┬─────┬─────┬─────┬─────┬─────┬───────┐
+ * │       │     │     │     │     │     │     │ Center keys │     │     │     │     │     │     │       │
+ * ├───────┼─────┼─────┼─────┼─────┼─────┼─────┤   ┌─────┐   ├─────┼─────┼─────┼─────┼─────┼─────┼───────┤
+ * │       │     │     │     │     │     │     │   │     │   │     │     │     │     │     │     │       │
+ * ├───────┼─────┼─────┼─────╆─────╅─────┤     │   ├─────┤   │     ├─────╆─────╅─────┼─────┼─────┼───────┤
+ * │       │     │     │     │     │     ├─────┤   │     │   ├─────┤     │     │     │     │     │       │
+ * ├───────┼─────┼─────┼─────╄─────╃─────┤     │   └─────┘   │     ├─────╄─────╃─────┼─────┼─────┼───────┤
+ * │       │     │     │     │     │     │     ├─────┐ ┌─────┤     │     │     │     │     │     │       │
+ * └┬──────┼─────┼─────┼─────┼─────┼─────┼─────┤     │ │     ├─────┼─────┼─────┼─────┼─────┼─────┼──────┬┘
+ *  │      │     │     │     │     │     │     ├─────┤ ├─────┤     │     │     │     │     │     │      │
+ *  └──────┴─────┴─────┴─────┤     │     │     │     │ │     │     │     │     ├─────┴─────┴─────┴──────┘
+ *                           └─────┴─────┴─────┴─────┘ └─────┴─────┴─────┴─────┘
+                  Left hand                                                     Right hand
+ */
+#define LAYOUT( \
+    k00, k01, k02, k03, k04, k05, k06,\
+    k10, k11, k12, k13, k14, k15, k16,\
+    k20, k21, k22, k23, k24, k25,\
+    k30, k31, k32, k33, k34, k35, k26, k37,\
+    k40, k41, k42, k43, k44, k45, k46, k47,\
+    \
+    k18,\
+    k28,\
+    \
+         k010, k011, k012, k013, k014, k015, k016,\
+         k110, k111, k112, k113, k114, k115, k116,\
+               k211, k212, k213, k214, k215, k216,\
+    k39, k210, k311, k312, k313, k314, k315, k316,\
+    k49, k410, k411, k412, k413, k414, k415, k416\
+) \
+{ \
+    {k00, k01, k02, k03, k04, k05, k06, KC_NO, KC_NO, KC_NO, k010, k011, k012, k013, k014, k015, k016},\
+    {k10, k11, k12, k13, k14, k15, k16, KC_NO, k18, KC_NO, k110, k111, k112, k113, k114, k115, k116},\
+    {k20, k21, k22, k23, k24, k25, k26, KC_NO, k28, KC_NO, k210, k211, k212, k213, k214, k215, k216},\
+    {k30, k31, k32, k33, k34, k35, KC_NO, k37, KC_NO, k39, KC_NO, k311, k312, k313, k314, k315, k316},\
+    {k40, k41, k42, k43, k44, k45, k46, k47, KC_NO, k49, k410, k411, k412, k413, k414, k415, k416},\
+}
+
+#define LAYOUT_flat( \
+    k00, k01, k02, k03, k04, k05, k06, k010, k011, k012, k013, k014, k015, k016,\
+    k10, k11, k12, k13, k14, k15, k16, k18, k110, k111, k112, k113, k114, k115, k116,\
+    k20, k21, k22, k23, k24, k25, k26, k28, k210, k211, k212, k213, k214, k215, k216,\
+    k30, k31, k32, k33, k34, k35, k37, k39, k311, k312, k313, k314, k315, k316,\
+    k40, k41, k42, k43, k44, k45, k46, k47, k49, k410, k411, k412, k413, k414, k415, k416\
+) \
+{ \
+    {k00, k01, k02, k03, k04, k05, k06, KC_NO, KC_NO, KC_NO, k010, k011, k012, k013, k014, k015, k016},\
+    {k10, k11, k12, k13, k14, k15, k16, KC_NO, k18, KC_NO, k110, k111, k112, k113, k114, k115, k116},\
+    {k20, k21, k22, k23, k24, k25, k26, KC_NO, k28, KC_NO, k210, k211, k212, k213, k214, k215, k216},\
+    {k30, k31, k32, k33, k34, k35, KC_NO, k37, KC_NO, k39, KC_NO, k311, k312, k313, k314, k315, k316},\
+    {k40, k41, k42, k43, k44, k45, k46, k47, KC_NO, k49, k410, k411, k412, k413, k414, k415, k416},\
+}
diff --git a/keyboards/aodox/config.h b/keyboards/aodox/config.h
new file mode 100644
index 0000000000..a408852589
--- /dev/null
+++ b/keyboards/aodox/config.h
@@ -0,0 +1,245 @@
+/*
+Copyright 2019 jxcrw
+
+This program is free software: you can redistribute it and/or modify
+it under the terms of the GNU General Public License as published by
+the Free Software Foundation, either version 2 of the License, or
+(at your option) any later version.
+
+This program is distributed in the hope that it will be useful,
+but WITHOUT ANY WARRANTY; without even the implied warranty of
+MERCHANTABILITY or FITNESS FOR A PARTICULAR PURPOSE.  See the
+GNU General Public License for more details.
+
+You should have received a copy of the GNU General Public License
+along with this program.  If not, see <http://www.gnu.org/licenses/>.
+*/
+
+#pragma once
+
+#include "config_common.h"
+
+/* USB Device descriptor parameter */
+#define VENDOR_ID 0xFEED
+#define PRODUCT_ID 0x6060
+#define DEVICE_VER 0x0001
+#define MANUFACTURER AOindustries
+#define PRODUCT AODox
+#define DESCRIPTION Ergonomic mech optimized for steno
+
+/* key matrix size */
+#define MATRIX_ROWS 5
+#define MATRIX_COLS 17
+
+/*
+ * Keyboard Matrix Assignments
+ *
+ * Change this to how you wired your keyboard
+ * ROWS: AVR pins used for rows, top to bottom
+ * COLS: AVR pins used for columns, left to right
+ * DIODE_DIRECTION: COL2ROW = COL = Anode (+), ROW = Cathode (-, marked on diode)
+ *                  ROW2COL = ROW = Anode (+), COL = Cathode (-, marked on diode)
+ *
+ */
+#define MATRIX_ROW_PINS {D4, D6, B4, B5, B6}
+#define MATRIX_COL_PINS {B0, B1, B2, B3, D1, D2, D3, D5, D7, C6, F7, F6, F5, F4, F1, F0, E6}
+#define UNUSED_PINS
+
+/* COL2ROW, ROW2COL*/
+#define DIODE_DIRECTION COL2ROW
+
+// #define BACKLIGHT_PIN B7
+// #define BACKLIGHT_BREATHING
+// #define BACKLIGHT_LEVELS 3
+
+// #define RGB_DI_PIN E2
+// #ifdef RGB_DI_PIN
+//   #define RGBLED_NUM 16
+//   #define RGBLIGHT_HUE_STEP 8
+//   #define RGBLIGHT_SAT_STEP 8
+//   #define RGBLIGHT_VAL_STEP 8
+//   #define RGBLIGHT_LIMIT_VAL 255 /* The maximum brightness level */
+//   #define RGBLIGHT_SLEEP  /* If defined, the RGB lighting will be switched off when the host goes to sleep */
+// /*== all animations enable ==*/
+//   #define RGBLIGHT_ANIMATIONS
+// /*== or choose animations ==*/
+//   #define RGBLIGHT_EFFECT_BREATHING
+//   #define RGBLIGHT_EFFECT_RAINBOW_MOOD
+//   #define RGBLIGHT_EFFECT_RAINBOW_SWIRL
+//   #define RGBLIGHT_EFFECT_SNAKE
+//   #define RGBLIGHT_EFFECT_KNIGHT
+//   #define RGBLIGHT_EFFECT_CHRISTMAS
+//   #define RGBLIGHT_EFFECT_STATIC_GRADIENT
+//   #define RGBLIGHT_EFFECT_RGB_TEST
+//   #define RGBLIGHT_EFFECT_ALTERNATING
+// /*== customize breathing effect ==*/
+//   /*==== (DEFAULT) use fixed table instead of exp() and sin() ====*/
+//   #define RGBLIGHT_BREATHE_TABLE_SIZE 256      // 256(default) or 128 or 64
+//   /*==== use exp() and sin() ====*/
+//   #define RGBLIGHT_EFFECT_BREATHE_CENTER 1.85  // 1 to 2.7
+//   #define RGBLIGHT_EFFECT_BREATHE_MAX    255   // 0 to 255
+// #endif
+
+/* Debounce reduces chatter (unintended double-presses) - set 0 if debouncing is not needed */
+#define DEBOUNCE 15
+#define TAPPING_TERM 117
+
+/* define if matrix has ghost (lacks anti-ghosting diodes) */
+//#define MATRIX_HAS_GHOST
+
+/* Mechanical locking support. Use KC_LCAP, KC_LNUM or KC_LSCR instead in keymap */
+#define LOCKING_SUPPORT_ENABLE
+/* Locking resynchronize hack */
+#define LOCKING_RESYNC_ENABLE
+
+/* If defined, GRAVE_ESC will always act as ESC when CTRL is held.
+ * This is userful for the Windows task manager shortcut (ctrl+shift+esc).
+ */
+// #define GRAVE_ESC_CTRL_OVERRIDE
+
+/*
+ * Force NKRO
+ *
+ * Force NKRO (nKey Rollover) to be enabled by default, regardless of the saved
+ * state in the bootmagic EEPROM settings. (Note that NKRO must be enabled in the
+ * makefile for this to work.)
+ *
+ * If forced on, NKRO can be disabled via magic key (default = LShift+RShift+N)
+ * until the next keyboard reset.
+ *
+ * NKRO may prevent your keystrokes from being detected in the BIOS, but it is
+ * fully operational during normal computer usage.
+ *
+ * For a less heavy-handed approach, enable NKRO via magic key (LShift+RShift+N)
+ * or via bootmagic (hold SPACE+N while plugging in the keyboard). Once set by
+ * bootmagic, NKRO mode will always be enabled until it is toggled again during a
+ * power-up.
+ *
+ */
+#define FORCE_NKRO
+
+/*
+ * Magic Key Options
+ *
+ * Magic keys are hotkey commands that allow control over firmware functions of
+ * the keyboard. They are best used in combination with the HID Listen program,
+ * found here: https://www.pjrc.com/teensy/hid_listen.html
+ *
+ * The options below allow the magic key functionality to be changed. This is
+ * useful if your keyboard/keypad is missing keys and you want magic key support.
+ *
+ */
+
+/* key combination for magic key command */
+/* defined by default; to change, uncomment and set to the combination you want */
+// #define IS_COMMAND() (get_mods() == MOD_MASK_SHIFT)
+
+/* control how magic key switches layers */
+//#define MAGIC_KEY_SWITCH_LAYER_WITH_FKEYS  true
+//#define MAGIC_KEY_SWITCH_LAYER_WITH_NKEYS  true
+//#define MAGIC_KEY_SWITCH_LAYER_WITH_CUSTOM false
+
+/* override magic key keymap */
+//#define MAGIC_KEY_SWITCH_LAYER_WITH_FKEYS
+//#define MAGIC_KEY_SWITCH_LAYER_WITH_NKEYS
+//#define MAGIC_KEY_SWITCH_LAYER_WITH_CUSTOM
+//#define MAGIC_KEY_HELP           H
+//#define MAGIC_KEY_HELP_ALT       SLASH
+//#define MAGIC_KEY_DEBUG          D
+//#define MAGIC_KEY_DEBUG_MATRIX   X
+//#define MAGIC_KEY_DEBUG_KBD      K
+//#define MAGIC_KEY_DEBUG_MOUSE    M
+//#define MAGIC_KEY_VERSION        V
+//#define MAGIC_KEY_STATUS         S
+//#define MAGIC_KEY_CONSOLE        C
+//#define MAGIC_KEY_LAYER0         0
+//#define MAGIC_KEY_LAYER0_ALT     GRAVE
+//#define MAGIC_KEY_LAYER1         1
+//#define MAGIC_KEY_LAYER2         2
+//#define MAGIC_KEY_LAYER3         3
+//#define MAGIC_KEY_LAYER4         4
+//#define MAGIC_KEY_LAYER5         5
+//#define MAGIC_KEY_LAYER6         6
+//#define MAGIC_KEY_LAYER7         7
+//#define MAGIC_KEY_LAYER8         8
+//#define MAGIC_KEY_LAYER9         9
+//#define MAGIC_KEY_BOOTLOADER     B
+//#define MAGIC_KEY_BOOTLOADER_ALT ESC
+//#define MAGIC_KEY_LOCK           CAPS
+//#define MAGIC_KEY_EEPROM         E
+//#define MAGIC_KEY_EEPROM_CLEAR   BSPACE
+//#define MAGIC_KEY_NKRO           N
+//#define MAGIC_KEY_SLEEP_LED      Z
+
+/*
+ * Feature disable options
+ *  These options are also useful to firmware size reduction.
+ */
+
+/* disable debug print */
+//#define NO_DEBUG
+
+/* disable print */
+//#define NO_PRINT
+
+/* disable action features */
+//#define NO_ACTION_LAYER
+//#define NO_ACTION_TAPPING
+//#define NO_ACTION_ONESHOT
+//#define NO_ACTION_MACRO
+//#define NO_ACTION_FUNCTION
+
+/*
+ * MIDI options
+ */
+
+/* Prevent use of disabled MIDI features in the keymap */
+//#define MIDI_ENABLE_STRICT 1
+
+/* enable basic MIDI features:
+   - MIDI notes can be sent when in Music mode is on
+*/
+//#define MIDI_BASIC
+
+/* enable advanced MIDI features:
+   - MIDI notes can be added to the keymap
+   - Octave shift and transpose
+   - Virtual sustain, portamento, and modulation wheel
+   - etc.
+*/
+//#define MIDI_ADVANCED
+
+/* override number of MIDI tone keycodes (each octave adds 12 keycodes and allocates 12 bytes) */
+//#define MIDI_TONE_KEYCODE_OCTAVES 1
+
+/*
+ * HD44780 LCD Display Configuration
+ */
+/*
+#define LCD_LINES           2     //< number of visible lines of the display
+#define LCD_DISP_LENGTH    16     //< visibles characters per line of the display
+
+#define LCD_IO_MODE      1            //< 0: memory mapped mode, 1: IO port mode
+
+#if LCD_IO_MODE
+#define LCD_PORT         PORTB        //< port for the LCD lines
+#define LCD_DATA0_PORT   LCD_PORT     //< port for 4bit data bit 0
+#define LCD_DATA1_PORT   LCD_PORT     //< port for 4bit data bit 1
+#define LCD_DATA2_PORT   LCD_PORT     //< port for 4bit data bit 2
+#define LCD_DATA3_PORT   LCD_PORT     //< port for 4bit data bit 3
+#define LCD_DATA0_PIN    4            //< pin for 4bit data bit 0
+#define LCD_DATA1_PIN    5            //< pin for 4bit data bit 1
+#define LCD_DATA2_PIN    6            //< pin for 4bit data bit 2
+#define LCD_DATA3_PIN    7            //< pin for 4bit data bit 3
+#define LCD_RS_PORT      LCD_PORT     //< port for RS line
+#define LCD_RS_PIN       3            //< pin  for RS line
+#define LCD_RW_PORT      LCD_PORT     //< port for RW line
+#define LCD_RW_PIN       2            //< pin  for RW line
+#define LCD_E_PORT       LCD_PORT     //< port for Enable line
+#define LCD_E_PIN        1            //< pin  for Enable line
+#endif
+*/
+
+/* Bootmagic Lite key configuration */
+// #define BOOTMAGIC_LITE_ROW 0
+// #define BOOTMAGIC_LITE_COLUMN 0
diff --git a/keyboards/aodox/info.json b/keyboards/aodox/info.json
new file mode 100644
index 0000000000..fde0ceb6d9
--- /dev/null
+++ b/keyboards/aodox/info.json
@@ -0,0 +1,18 @@
+{
+    "keyboard_name": "AODox",
+    "url": "",
+    "maintainer": "jxcrw",
+    "width": 3,
+    "height": 2,
+    "layouts": {
+        "LAYOUT": {
+            "layout": [
+                {"label":"k00", "x":0, "y":0},
+                {"label":"k01", "x":1, "y":0},
+                {"label":"k02", "x":2, "y":0},
+                {"label":"k10", "x":0, "y":1, "w":1.5},
+                {"label":"k12", "x":1.5, "y":1, "w":1.5}
+            ]
+        }
+    }
+}
diff --git a/keyboards/aodox/keymaps/default/config.h b/keyboards/aodox/keymaps/default/config.h
new file mode 100644
index 0000000000..05aef1702d
--- /dev/null
+++ b/keyboards/aodox/keymaps/default/config.h
@@ -0,0 +1,19 @@
+/* Copyright 2019 jxcrw
+ *
+ * This program is free software: you can redistribute it and/or modify
+ * it under the terms of the GNU General Public License as published by
+ * the Free Software Foundation, either version 2 of the License, or
+ * (at your option) any later version.
+ *
+ * This program is distributed in the hope that it will be useful,
+ * but WITHOUT ANY WARRANTY; without even the implied warranty of
+ * MERCHANTABILITY or FITNESS FOR A PARTICULAR PURPOSE.  See the
+ * GNU General Public License for more details.
+ *
+ * You should have received a copy of the GNU General Public License
+ * along with this program.  If not, see <http://www.gnu.org/licenses/>.
+ */
+
+#pragma once
+
+// place overrides here
diff --git a/keyboards/aodox/keymaps/default/keymap.c b/keyboards/aodox/keymaps/default/keymap.c
new file mode 100644
index 0000000000..00346e0278
--- /dev/null
+++ b/keyboards/aodox/keymaps/default/keymap.c
@@ -0,0 +1,279 @@
+/* Copyright 2019 jxcrw
+ *
+ * This program is free software: you can redistribute it and/or modify
+ * it under the terms of the GNU General Public License as published by
+ * the Free Software Foundation, either version 2 of the License, or
+ * (at your option) any later version.
+ *
+ * This program is distributed in the hope that it will be useful,
+ * but WITHOUT ANY WARRANTY; without even the implied warranty of
+ * MERCHANTABILITY or FITNESS FOR A PARTICULAR PURPOSE.  See the
+ * GNU General Public License for more details.
+ *
+ * You should have received a copy of the GNU General Public License
+ * along with this program.  If not, see <http://www.gnu.org/licenses/>.
+ */
+#include QMK_KEYBOARD_H
+
+// Defines names for use in layer keycodes and the keymap
+enum AODox_layers {
+    STNO,
+    SNPD,
+    QWTY,
+    QSYM,
+    MDIA,
+};
+
+// Defines the keycodes used by our macros in process_record_user
+enum custom_keycodes {
+    QMKBEST = SAFE_RANGE,
+    QMKURL
+};
+
+const uint16_t PROGMEM keymaps[][MATRIX_ROWS][MATRIX_COLS] = {
+/*Steno
+ * ┌───────┬─────┬─────┬─────┬─────┬─────┬─────┐             ┌─────┬─────┬─────┬─────┬─────┬─────┬───────┐
+ * │   -   │ F1  │ F2  │ F3  │ F4  │ F5  │QWTY │ Center keys │ F13 │  F6 │  F7 │  F8 │  F9 │ F10 │   ~   │
+ * ├───────┼─────┼─────┼─────┼─────┼─────┼─────┤   ┌─────┐   ├─────┼─────┼─────┼─────┼─────┼─────┼───────┤
+ * │Ent/MDA│  Q  │  W  │  E  │  R  │  T  │ F14 │   │     │   │     │  Y  │  U  │  I  │  O  │  P  │  F22  │
+ * ├───────┼─────┼─────┼─────╆─────╅─────┤     │   ├─────┤   │     ├─────╆─────╅─────┼─────┼─────┼───────┤
+ * │Tab/SYM│  A  │  S  │  D  │  F  │  G  ├─────┤   │     │   ├─────┤  H  │  ←  │  ↓  │  ↑  │  →  │   "   │
+ * ├───────┼─────┼─────┼─────╄─────╃─────┤Esc/ │   └─────┘   │  K/ ├─────╄─────╃─────┼─────┼─────┼───────┤
+ * │  F15  │  Z  │  X  │  C  │  V  │  B  │LCAG ├─────┐ ┌─────┤ LCAG│  N  │  M  │  ,  │  .  │  ?  │  F23  │
+ * └┬──────┼─────┼─────┼─────┼─────┼─────┼─────┤PgUp │ │ PgDn├─────┼─────┼─────┼─────┼─────┼─────┼──────┬┘
+ *  │ LGui │Dl/Al│Bp/Sf│Sp/Cl│ F16 │ F17 │ F18 ├─────┤ ├─────┤ F19 │ F20 │ F21 │Sp/Cl│Bp/Sf│Is/Al│ PtSc │
+ *  └──────┴─────┴─────┴─────┤     │     │     │Hm/Hp│ │Ed/Mh│     │     │     ├─────┴─────┴─────┴──────┘
+ *                           └─────┴─────┴─────┴─────┘ └─────┴─────┴─────┴─────┘
+                  Left hand                                                     Right hand
+ */
+[STNO] = LAYOUT(
+    // Left hand
+    KC_MINS,              KC_F1,          KC_F2,         KC_F3,     KC_F4,  KC_F5,  TG(QWTY),
+    LT(MDIA, KC_ENT),     KC_Q,           KC_W,          KC_E,      KC_R,   KC_T,   KC_F14,
+    LT(SNPD, KC_TAB),     KC_A,           KC_S,          KC_D,      KC_F,   KC_G,
+    KC_F15,               KC_Z,           KC_X,          KC_C,      KC_V,   KC_B,   LCAG_T(KC_ESC), KC_PGUP,
+    KC_LGUI,         ALT_T(KC_DELT), SFT_T(KC_BSPC), CTL_T(KC_SPC), KC_F16, KC_F17, KC_F18,         ALL_T(KC_HOME),
+
+    // Center keys
+    TG(QWTY),
+    KC_TRNS,
+
+    // Right hand
+                      KC_F13,    KC_F6,   KC_F7,    KC_F8,         KC_F9,          KC_F10,     KC_GRV,
+                      KC_NO,     KC_Y,    KC_U,     KC_I,          KC_O,            KC_P,      KC_F22,
+                                 KC_H,   KC_LEFT,  KC_DOWN,        KC_UP,          KC_RGHT,    KC_QUOT,
+    KC_PGDN,       LCAG_T(KC_K), KC_N,    KC_M,    KC_COMM,        KC_DOT,         KC_SLSH,    KC_F23,
+    MEH_T(KC_END),    KC_F19,    KC_F20, KC_F21, CTL_T(KC_SPC), SFT_T(KC_BSPC), ALT_T(KC_INS), KC_PSCR
+),
+
+/* Steno numpad
+ * ┌───────┬─────┬─────┬─────┬─────┬─────┬─────┐             ┌─────┬─────┬─────┬─────┬─────┬─────┬───────┐
+ * │       │     │     │     │     │     │     │ Center keys │NumLk│     │     │     │     │ F11 │  F12  │
+ * ├───────┼─────┼─────┼─────┼─────┼─────┼─────┤   ┌─────┐   ├─────┼─────┼─────┼─────┼─────┼─────┼───────┤
+ * │       │     │     │     │     │     │     │   │     │   │ CALC│  :  │  7  │  8  │  9  │  *  │   \   │
+ * ├───────┼─────┼─────┼─────╆─────╅─────┤     │   ├─────┤   │     ├─────╆─────╅─────┼─────┼─────┼───────┤
+ * │       │     │     │     │     │     ├─────┤   │     │   ├─────┤  .  │  4  │  5  │  6  │  +  │   -   │
+ * ├───────┼─────┼─────┼─────╄─────╃─────┤     │   └─────┘   │     ├─────╄─────╃─────┼─────┼─────┼───────┤
+ * │       │     │     │     │     │     │     ├─────┐ ┌─────┤     │  ,  │  1  │  2  │  3  │  /  │       │
+ * └┬──────┼─────┼─────┼─────┼─────┼─────┼─────┤     │ │     ├─────┼─────┼─────┼─────┼─────┼─────┼──────┬┘
+ *  │      │     │     │     │     │     │     ├─────┤ ├─────┤     │     │  0  │     │     │     │      │
+ *  └──────┴─────┴─────┴─────┤     │     │     │     │ │     │     │     │     ├─────┴─────┴─────┴──────┘
+ *                           └─────┴─────┴─────┴─────┘ └─────┴─────┴─────┴─────┘
+                  Left hand                                                     Right hand
+ */
+[SNPD] = LAYOUT(
+    // Left hand
+    KC_TRNS, KC_TRNS, KC_TRNS, KC_TRNS, KC_TRNS, KC_TRNS, KC_TRNS,
+    KC_TRNS, KC_TRNS, KC_TRNS, KC_TRNS, KC_TRNS, KC_TRNS, KC_TRNS,
+    KC_TRNS, KC_TRNS, KC_TRNS, KC_TRNS, KC_TRNS, KC_TRNS,
+    KC_TRNS, KC_TRNS, KC_TRNS, KC_TRNS, KC_TRNS, KC_TRNS, KC_TRNS, KC_TRNS,
+    KC_TRNS, KC_TRNS, KC_TRNS, KC_TRNS, KC_TRNS, KC_TRNS, KC_TRNS, KC_TRNS,
+
+    // Center keys
+    KC_TRNS,
+    KC_TRNS,
+
+    // Right hand
+             KC_NLCK, KC_TRNS, KC_TRNS, KC_TRNS, KC_TRNS, KC_F11,  KC_F12,
+             KC_CALC, KC_COLN,  KC_7,    KC_8,    KC_9,   KC_PAST, KC_BSLS,
+                      KC_PDOT,  KC_4,    KC_5,    KC_6,   KC_PPLS, KC_PMNS,
+    KC_TRNS, KC_TRNS, KC_TRNS,  KC_1,    KC_2,    KC_3,   KC_TRNS, KC_TRNS,
+    KC_TRNS, KC_TRNS, KC_TRNS,  KC_0,   KC_TRNS, KC_TRNS, KC_TRNS, KC_TRNS
+),
+
+/* Qwerty layout
+ * ┌───────┬─────┬─────┬─────┬─────┬─────┬─────┐             ┌─────┬─────┬─────┬─────┬─────┬─────┬───────┐
+ * │   -   │ F1  │ F2  │ F3  │ F4  │ F5  │     │ Center keys │ F13 │  F6 │  F7 │  F8 │  F9 │ F10 │   ~   │
+ * ├───────┼─────┼─────┼─────┼─────┼─────┼─────┤   ┌─────┐   ├─────┼─────┼─────┼─────┼─────┼─────┼───────┤
+ * │Ent/MDA│  Q  │  W  │  E  │  R  │  T  │ F14 │   │     │   │ CALC│  Y  │  U  │  I  │  O  │  P  │   \   │
+ * ├───────┼─────┼─────┼─────╆─────╅─────┤     │   ├─────┤   │     ├─────╆─────╅─────┼─────┼─────┼───────┤
+ * │Tab/SYM│  A  │  S  │  D  │  F  │  G  ├─────┤   │ Ins │   ├─────┤  H  │  J  │  K  │  L  │  ;  │ "/SYM │
+ * ├───────┼─────┼─────┼─────╄─────╃─────┤Esc/ │   └─────┘   │  K/ ├─────╄─────╃─────┼─────┼─────┼───────┤
+ * │ (/Sft │  Z  │  X  │  C  │  V  │  B  │LCAG ├─────┐ ┌─────┤ LCAG│  N  │  M  │  ,  │  .  │  ?  │ )/Sft │
+ * └┬──────┼─────┼─────┼─────┼─────┼─────┼─────┤PgUp │ │ PgDn├─────┼─────┼─────┼─────┼─────┼─────┼──────┬┘
+ *  │ LGui │Dl/Al│Bp/Sf│Sp/Cl│ F16 │ Bsp │ Dlt ├─────┤ ├─────┤ F19 │ Spc │  ←  │ ↓/Cl│ ↑/Sf│ →/Al│ PtSc │
+ *  └──────┴─────┴─────┴─────┤     │     │     │Hm/Hp│ │Ed/Mh│     │     │     ├─────┴─────┴─────┴──────┘
+ *                           └─────┴─────┴─────┴─────┘ └─────┴─────┴─────┴─────┘
+                  Left hand                                                     Right hand
+ */
+[QWTY] = LAYOUT(
+    // Left hand
+    KC_MINS,              KC_F1,          KC_F2,         KC_F3,     KC_F4,  KC_F5,   KC_TRNS,
+    LT(MDIA, KC_ENT),     KC_Q,           KC_W,          KC_E,      KC_R,   KC_T,    KC_F14,
+    LT(QSYM, KC_TAB),     KC_A,           KC_S,          KC_D,      KC_F,   KC_G,
+    KC_LSPO,              KC_Z,           KC_X,          KC_C,      KC_V,   KC_B,    LCAG_T(KC_ESC), KC_PGUP,
+    KC_LGUI,         ALT_T(KC_DELT), SFT_T(KC_BSPC), CTL_T(KC_SPC), KC_F16, KC_BSPC, KC_DELT,        ALL_T(KC_HOME),
+
+    // Center keys
+    KC_TRNS,
+    KC_INS,
+
+    // Right hand
+                      KC_F13,    KC_F6,   KC_F7,    KC_F8,          KC_F9,        KC_F10,       KC_GRV,
+                      KC_ENT,    KC_Y,    KC_U,     KC_I,           KC_O,          KC_P,        KC_BSLS,
+                                 KC_H,    KC_J,     KC_K,           KC_L,         KC_SCLN,      LT(QSYM, KC_QUOT),
+    KC_PGDN,       LCAG_T(KC_K), KC_N,    KC_M,    KC_COMM,         KC_DOT,       KC_SLSH,      KC_RSPC,
+    MEH_T(KC_END),    KC_F19,    KC_SPC, KC_LEFT, CTL_T(KC_DOWN), SFT_T(KC_UP), ALT_T(KC_RGHT), KC_PSCR
+),
+
+/* Qwerty symbols
+ * ┌───────┬─────┬─────┬─────┬─────┬─────┬─────┐             ┌─────┬─────┬─────┬─────┬─────┬─────┬───────┐
+ * │       │     │     │     │     │     │     │ Center keys │     │     │     │     │     │     │       │
+ * ├───────┼─────┼─────┼─────┼─────┼─────┼─────┤   ┌─────┐   ├─────┼─────┼─────┼─────┼─────┼─────┼───────┤
+ * │       │  #  │  @  │  {  │  }  │  |  │     │   │     │   │     │  -  │  7  │  8  │  9  │  *  │   \   │
+ * ├───────┼─────┼─────┼─────╆─────╅─────┤     │   ├─────┤   │     ├─────╆─────╅─────┼─────┼─────┼───────┤
+ * │       │  !  │  $  │  [  │  ]  │  `  ├─────┤   │     │   ├─────┤  :  │  4  │  5  │  6  │  +  │   -   │
+ * ├───────┼─────┼─────┼─────╄─────╃─────┤     │   └─────┘   │     ├─────╄─────╃─────┼─────┼─────┼───────┤
+ * │       │  %  │  ^  │  &  │  =  │     │     ├─────┐ ┌─────┤     │  ,  │  1  │  2  │  3  │  /  │       │
+ * └┬──────┼─────┼─────┼─────┼─────┼─────┼─────┤     │ │     ├─────┼─────┼─────┼─────┼─────┼─────┼──────┬┘
+ *  │      │     │     │     │     │  .  │     ├─────┤ ├─────┤     │     │  0  │  ↓  │  ↑  │     │      │
+ *  └──────┴─────┴─────┴─────┤     │     │     │     │ │     │     │     │     ├─────┴─────┴─────┴──────┘
+ *                           └─────┴─────┴─────┴─────┘ └─────┴─────┴─────┴─────┘
+                  Left hand                                                     Right hand
+ */
+[QSYM] = LAYOUT(
+    // Left hand
+    KC_TRNS, KC_TRNS, KC_TRNS, KC_TRNS, KC_TRNS, KC_TRNS, KC_TRNS,
+    KC_TRNS, KC_HASH,  KC_AT,  KC_LCBR, KC_RCBR, KC_PIPE, KC_TRNS,
+    KC_TRNS, KC_EXLM, KC_DLR,  KC_LBRC, KC_RBRC, KC_G,
+    KC_TRNS, KC_PERC, KC_CIRC, KC_AMPR, KC_EQL,  KC_TRNS, KC_TRNS, KC_TRNS,
+    KC_TRNS, KC_TRNS, KC_TRNS, KC_TRNS, KC_TRNS, KC_PDOT, KC_TRNS, KC_TRNS,
+
+    // Center keys
+    KC_TRNS,
+    KC_TRNS,
+
+    // Right hand
+             KC_TRNS, KC_TRNS, KC_TRNS, KC_TRNS, KC_TRNS, KC_TRNS, KC_TRNS,
+             KC_CALC, KC_MINS,   KC_7,    KC_8,    KC_9,  KC_ASTR, KC_BSLS,
+                      KC_COLN,   KC_4,    KC_5,    KC_6,  KC_PPLS, KC_MINS,
+    KC_TRNS, KC_TRNS, KC_COMM,   KC_1,    KC_2,    KC_3,  KC_TRNS, KC_TRNS,
+    KC_TRNS, KC_TRNS, KC_TRNS,   KC_0,  KC_TRNS, KC_TRNS, KC_TRNS, KC_TRNS
+),
+
+/* Media, power, and RESET
+ * ┌───────┬─────┬─────┬─────┬─────┬─────┬─────┐             ┌─────┬─────┬─────┬─────┬─────┬─────┬───────┐
+ * │       │     │     │     │     │     │     │ Center keys │     │     │     │     │     │     │ RESET │
+ * ├───────┼─────┼─────┼─────┼─────┼─────┼─────┤   ┌─────┐   ├─────┼─────┼─────┼─────┼─────┼─────┼───────┤
+ * │       │     │     │     │VolUp│     │     │   │SLEEP│   │     │     │     │     │     │     │       │
+ * ├───────┼─────┼─────┼─────╆─────╅─────┤     │   ├─────┤   │     ├─────╆─────╅─────┼─────┼─────┼───────┤
+ * │       │     │Prev │Next │VolDn│     ├─────┤   │ WAKE│   ├─────┤     │     │     │     │     │ POWER │
+ * ├───────┼─────┼─────┼─────╄─────╃─────┤     │   └─────┘   │     ├─────╄─────╃─────┼─────┼─────┼───────┤
+ * │       │     │     │     │Mute │     │     ├─────┐ ┌─────┤     │     │     │     │     │     │       │
+ * └┬──────┼─────┼─────┼─────┼─────┼─────┼─────┤     │ │     ├─────┼─────┼─────┼─────┼─────┼─────┼──────┬┘
+ *  │      │     │     │     │Play/│     │     ├─────┤ ├─────┤     │     │     │     │     │     │      │
+ *  └──────┴─────┴─────┴─────┤Pause│     │     │     │ │     │     │     │     ├─────┴─────┴─────┴──────┘
+ *                           └─────┴─────┴─────┴─────┘ └─────┴─────┴─────┴─────┘
+                  Left hand                                                     Right hand
+ */
+[MDIA] = LAYOUT(
+    // Left hand
+    KC_TRNS, KC_TRNS, KC_TRNS, KC_TRNS, KC_TRNS, KC_TRNS, KC_TRNS,
+    KC_TRNS, KC_TRNS, KC_TRNS, KC_TRNS, KC_VOLU, KC_TRNS, KC_TRNS,
+    KC_TRNS, KC_TRNS, KC_MPRV, KC_MNXT, KC_VOLD, KC_TRNS,
+    KC_TRNS, KC_TRNS, KC_TRNS, KC_TRNS, KC_MUTE, KC_TRNS, KC_TRNS, KC_TRNS,
+    KC_TRNS, KC_TRNS, KC_TRNS, KC_TRNS, KC_TRNS, KC_MPLY, KC_TRNS, KC_TRNS,
+
+    // Center keys
+    KC_SLEP,
+    KC_WAKE,
+
+    // Right hand
+             KC_TRNS, KC_TRNS, KC_TRNS, KC_TRNS, KC_TRNS, KC_TRNS, RESET,
+             KC_TRNS, KC_TRNS, KC_TRNS, KC_TRNS, KC_TRNS, KC_TRNS, KC_TRNS,
+                      KC_TRNS, KC_TRNS, KC_TRNS, KC_TRNS, KC_TRNS, KC_PWR,
+    KC_TRNS, KC_TRNS, KC_TRNS, KC_TRNS, KC_TRNS, KC_TRNS, KC_TRNS, KC_TRNS,
+    KC_TRNS, KC_TRNS, KC_TRNS, KC_TRNS, KC_TRNS, KC_TRNS, KC_TRNS, KC_TRNS
+),
+
+/* Blank layer
+ * ┌───────┬─────┬─────┬─────┬─────┬─────┬─────┐             ┌─────┬─────┬─────┬─────┬─────┬─────┬───────┐
+ * │       │     │     │     │     │     │     │ Center keys │     │     │     │     │     │     │       │
+ * ├───────┼─────┼─────┼─────┼─────┼─────┼─────┤   ┌─────┐   ├─────┼─────┼─────┼─────┼─────┼─────┼───────┤
+ * │       │     │     │     │     │     │     │   │     │   │     │     │     │     │     │     │       │
+ * ├───────┼─────┼─────┼─────╆─────╅─────┤     │   ├─────┤   │     ├─────╆─────╅─────┼─────┼─────┼───────┤
+ * │       │     │     │     │     │     ├─────┤   │     │   ├─────┤     │     │     │     │     │       │
+ * ├───────┼─────┼─────┼─────╄─────╃─────┤     │   └─────┘   │     ├─────╄─────╃─────┼─────┼─────┼───────┤
+ * │       │     │     │     │     │     │     ├─────┐ ┌─────┤     │     │     │     │     │     │       │
+ * └┬──────┼─────┼─────┼─────┼─────┼─────┼─────┤     │ │     ├─────┼─────┼─────┼─────┼─────┼─────┼──────┬┘
+ *  │      │     │     │     │     │     │     ├─────┤ ├─────┤     │     │     │     │     │     │      │
+ *  └──────┴─────┴─────┴─────┤     │     │     │     │ │     │     │     │     ├─────┴─────┴─────┴──────┘
+ *                           └─────┴─────┴─────┴─────┘ └─────┴─────┴─────┴─────┘
+                  Left hand                                                     Right hand
+ */
+// [BLNK] = LAYOUT(
+//     // Left hand
+//     KC_TRNS, KC_TRNS, KC_TRNS, KC_TRNS, KC_TRNS, KC_TRNS, KC_TRNS,
+//     KC_TRNS, KC_TRNS, KC_TRNS, KC_TRNS, KC_TRNS, KC_TRNS, KC_TRNS,
+//     KC_TRNS, KC_TRNS, KC_TRNS, KC_TRNS, KC_TRNS, KC_TRNS,
+//     KC_TRNS, KC_TRNS, KC_TRNS, KC_TRNS, KC_TRNS, KC_TRNS, KC_TRNS, KC_TRNS,
+//     KC_TRNS, KC_TRNS, KC_TRNS, KC_TRNS, KC_TRNS, KC_TRNS, KC_TRNS, KC_TRNS,
+
+//     // Center keys
+//     KC_TRNS,
+//     KC_TRNS,
+
+//     // Right hand
+//              KC_TRNS, KC_TRNS, KC_TRNS, KC_TRNS, KC_TRNS, KC_TRNS, KC_TRNS,
+//              KC_TRNS, KC_TRNS, KC_TRNS, KC_TRNS, KC_TRNS, KC_TRNS, KC_TRNS,
+//                       KC_TRNS, KC_TRNS, KC_TRNS, KC_TRNS, KC_TRNS, KC_TRNS,
+//     KC_TRNS, KC_TRNS, KC_TRNS, KC_TRNS, KC_TRNS, KC_TRNS, KC_TRNS, KC_TRNS,
+//     KC_TRNS, KC_TRNS, KC_TRNS, KC_TRNS, KC_TRNS, KC_TRNS, KC_TRNS, KC_TRNS
+// ),
+};
+
+bool process_record_user(uint16_t keycode, keyrecord_t *record) {
+    switch (keycode) {
+        case QMKBEST:
+            if (record->event.pressed) {
+                // when keycode QMKBEST is pressed
+                SEND_STRING("QMK is the best thing ever!");
+            } else {
+                // when keycode QMKBEST is released
+            }
+            break;
+        case QMKURL:
+            if (record->event.pressed) {
+                // when keycode QMKURL is pressed
+                SEND_STRING("https://qmk.fm/" SS_TAP(X_ENTER));
+            } else {
+                // when keycode QMKURL is released
+            }
+            break;
+    }
+    return true;
+}
+
+/*
+void matrix_init_user(void) {
+
+}
+
+void matrix_scan_user(void) {
+
+}
+
+bool led_update_user(led_t led_state) {
+    return true;
+}
+*/
diff --git a/keyboards/aodox/keymaps/default/readme.md b/keyboards/aodox/keymaps/default/readme.md
new file mode 100644
index 0000000000..fc452b4624
--- /dev/null
+++ b/keyboards/aodox/keymaps/default/readme.md
@@ -0,0 +1 @@
+# The default keymap for AODox
diff --git a/keyboards/aodox/readme.md b/keyboards/aodox/readme.md
new file mode 100644
index 0000000000..1f96e32a77
--- /dev/null
+++ b/keyboards/aodox/readme.md
@@ -0,0 +1,15 @@
+# AODox
+
+AODox
+
+A short description of the keyboard/project
+
+* Keyboard Maintainer: [jxcrw](https://github.com/yourusername)
+* Hardware Supported: The PCBs, controllers supported
+* Hardware Availability: Links to where you can find this hardware
+
+Make example for this keyboard (after setting up your build environment):
+
+    make AODox:default
+
+See the [build environment setup](https://docs.qmk.fm/#/getting_started_build_tools) and the [make instructions](https://docs.qmk.fm/#/getting_started_make_guide) for more information. Brand new to QMK? Start with our [Complete Newbs Guide](https://docs.qmk.fm/#/newbs).
diff --git a/keyboards/aodox/rules.mk b/keyboards/aodox/rules.mk
new file mode 100644
index 0000000000..35be9ca64c
--- /dev/null
+++ b/keyboards/aodox/rules.mk
@@ -0,0 +1,42 @@
+# MCU name
+MCU = atmega32u4
+
+# Bootloader selection
+#   Teensy       halfkay
+#   Pro Micro    caterina
+#   Atmel DFU    atmel-dfu
+#   LUFA DFU     lufa-dfu
+#   QMK DFU      qmk-dfu
+#   ATmega32A    bootloadHID
+#   ATmega328P   USBasp
+BOOTLOADER = caterina
+
+# If you don't know the bootloader type, then you can specify the
+# Boot Section Size in *bytes* by uncommenting out the OPT_DEFS line
+# Otherwise, delete this section
+#   Teensy halfKay      512
+#   Teensy++ halfKay    1024
+#   Atmel DFU loader    4096
+#   LUFA bootloader     4096
+#   USBaspLoader        2048
+# OPT_DEFS += -DBOOTLOADER_SIZE=4096
+
+# Build Options
+#   change yes to no to disable
+#
+BOOTMAGIC_ENABLE = no       # Virtual DIP switch configuration
+MOUSEKEY_ENABLE = yes       # Mouse keys
+EXTRAKEY_ENABLE = yes       # Audio control and System control
+CONSOLE_ENABLE = yes        # Console for debug
+COMMAND_ENABLE = yes        # Commands for debug and configuration
+# Do not enable SLEEP_LED_ENABLE. it uses the same timer as BACKLIGHT_ENABLE
+SLEEP_LED_ENABLE = no       # Breathing sleep LED during USB suspend
+# if this doesn't work, see here: https://github.com/tmk/tmk_keyboard/wiki/FAQ#nkro-doesnt-work
+NKRO_ENABLE = yes            # USB Nkey Rollover
+BACKLIGHT_ENABLE = no       # Enable keyboard backlight functionality
+RGBLIGHT_ENABLE = no        # Enable keyboard RGB underglow
+MIDI_ENABLE = no            # MIDI support
+BLUETOOTH_ENABLE = no       # Enable Bluetooth with the Adafruit EZ-Key HID
+AUDIO_ENABLE = no           # Audio output on port C6
+FAUXCLICKY_ENABLE = no      # Use buzzer to emulate clicky switches
+HD44780_ENABLE = no         # Enable support for HD44780 based LCDs

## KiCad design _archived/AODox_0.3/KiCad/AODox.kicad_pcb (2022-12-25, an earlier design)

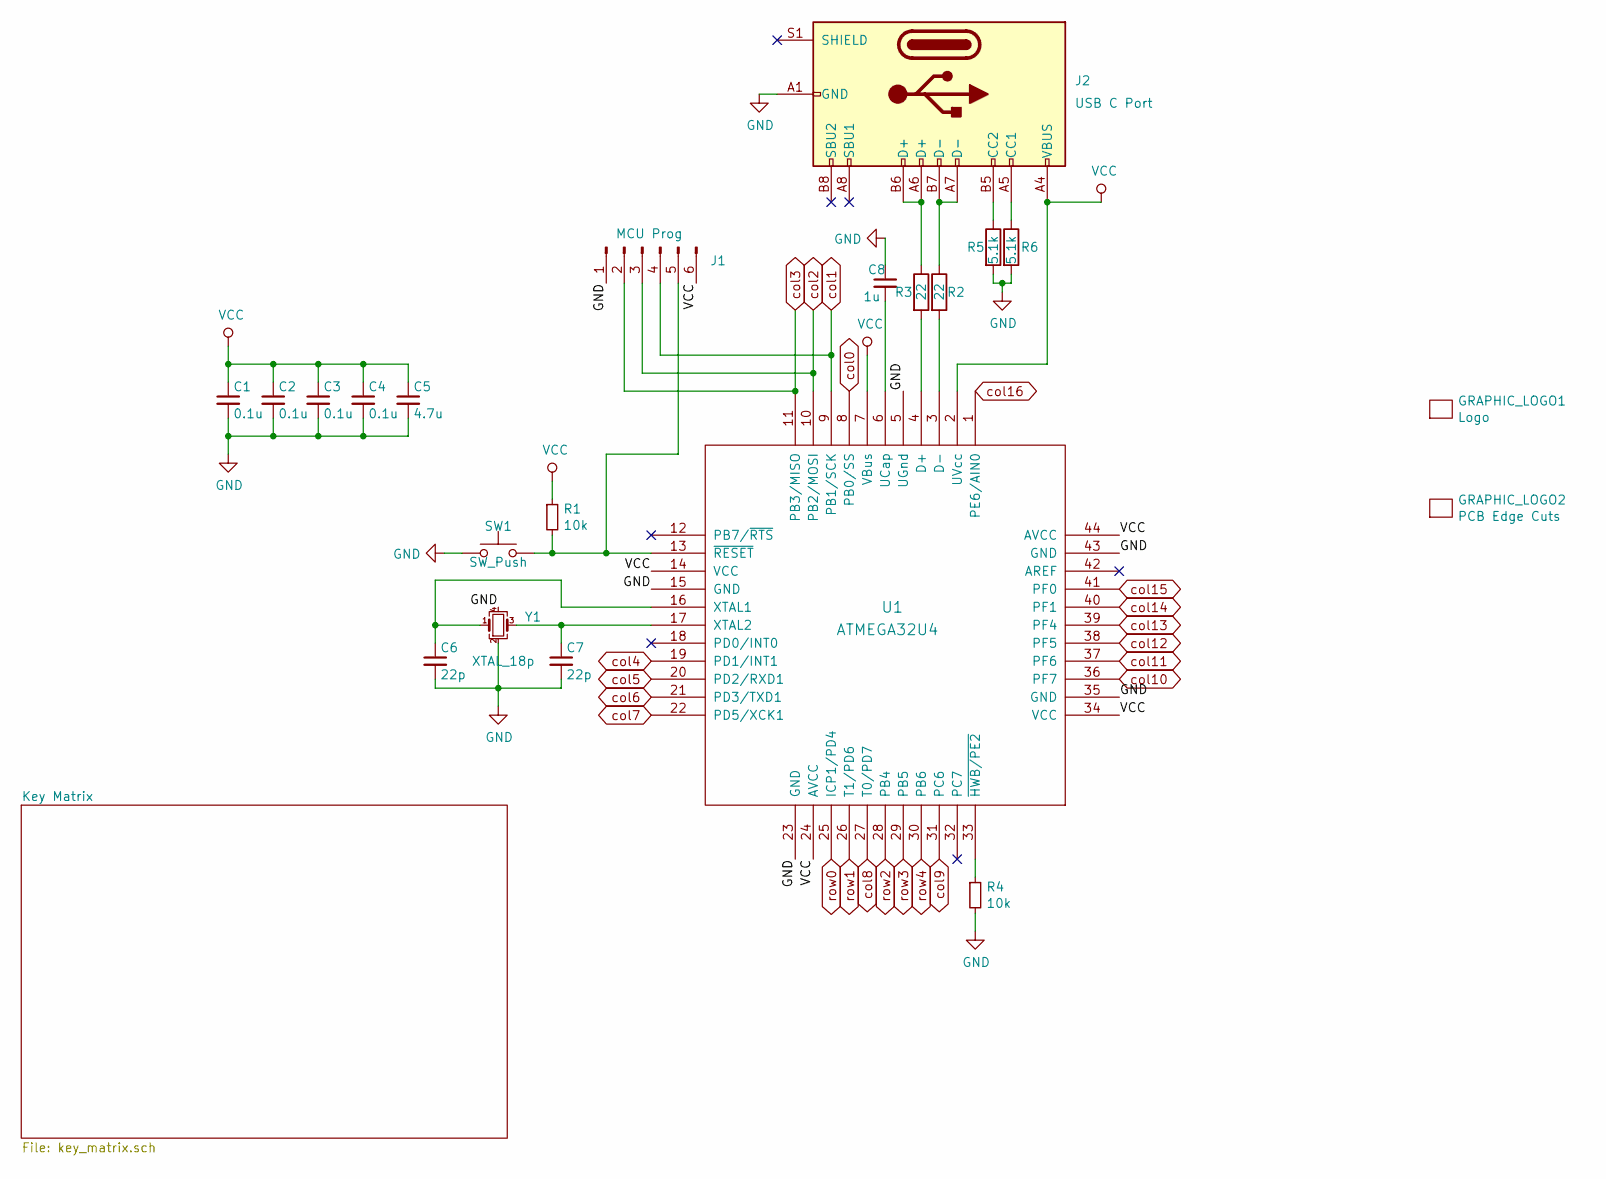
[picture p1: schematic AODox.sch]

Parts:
C1, C2, C3, C4: 0.1u; C_0805_2012Metric_Pad1.15x1.40mm_HandSolder
C5: 4.7u; C_0805_2012Metric_Pad1.15x1.40mm_HandSolder
C6, C7: 22p; C_0805_2012Metric_Pad1.15x1.40mm_HandSolder
C8: 1u; C_0805_2012Metric_Pad1.15x1.40mm_HandSolder
GRAPHIC_LOGO1: Logo; AODox_PCB_logo_Anurati
GRAPHIC_LOGO2: PCB Edge Cuts; PCB_edgecuts
J1: MCU Prog; PinHeader_1x06_P2.54mm_Vertical
J2: USB C Port; USB_C_Receptacle_GCT_USB4085
R1, R4: 10k; R_0805_2012Metric_Pad1.15x1.40mm_HandSolder
R2, R3: 22; R_0805_2012Metric_Pad1.15x1.40mm_HandSolder
R5, R6: 5.1k; R_0805_2012Metric_Pad1.15x1.40mm_HandSolder
SW1: SW_Push; SW_SPST_CK_KXT3
U1: ATMEGA32U4; TQFP-44_10x10mm_P0.8mm_HandSolder
Y1: XTAL_18p; Crystal_SMD_SeikoEpson_FA238-4Pin_3.2x2.5mm_HandSoldering

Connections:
GND: C1.2, C2.2, C3.2, C4.2, C5.2, C6.2, C7.2, C8.1, J1.1, J2.A1 (GND), J2.A12 (GND), J2.B1 (GND), J2.B12 (GND), R4.2, R5.2, R6.2, SW1.1, U1.5 (UGnd), U1.15 (GND), U1.23 (GND), U1.35 (GND), U1.43 (GND), Y1.2, Y1.4
unnamed: C6.1, U1.16 (XTAL1), Y1.1
unnamed: C7.1, U1.17 (XTAL2), Y1.3
unnamed: C8.2, U1.6 (UCap)
unnamed: J1.5, R1.2, SW1.2, U1.13 (~RESET)
unnamed: J2.A5 (CC1), R6.1
unnamed: J2.A6 (D+), J2.B6 (D+), R3.1
unnamed: J2.A7 (D-), J2.B7 (D-), R2.1
unnamed: J2.B5 (CC2), R5.1
unnamed: R2.2, U1.3 (D-)
unnamed: R3.2, U1.4 (D+)
unnamed: R4.1, U1.33 (~HWB/PE2)
VCC: C1.1, C2.1, C3.1, C4.1, C5.1, J1.6, J2.A4 (VBUS), J2.A9 (VBUS), J2.B4 (VBUS), J2.B9 (VBUS), R1.1, U1.2 (UVcc), U1.7 (VBus), U1.14 (VCC), U1.24 (AVCC), U1.34 (VCC), U1.44 (AVCC)
col0: U1.8 (PB0/SS); also elsewhere on the board
col1: J1.4, U1.9 (PB1/SCK); also elsewhere on the board
col2: J1.3, U1.10 (PB2/MOSI); also elsewhere on the board
col3: J1.2, U1.11 (PB3/MISO); also elsewhere on the board
col4: U1.19 (PD1/INT1); also elsewhere on the board
col5: U1.20 (PD2/RXD1); also elsewhere on the board
col6: U1.21 (PD3/TXD1); also elsewhere on the board
col7: U1.22 (PD5/XCK1); also elsewhere on the board
col8: U1.27 (T0/PD7); also elsewhere on the board
col9: U1.31 (PC6); also elsewhere on the board
col10: U1.36 (PF7); also elsewhere on the board
col11: U1.37 (PF6); also elsewhere on the board
col12: U1.38 (PF5); also elsewhere on the board
col13: U1.39 (PF4); also elsewhere on the board
col14: U1.40 (PF1); also elsewhere on the board
col15: U1.41 (PF0); also elsewhere on the board
col16: U1.1 (PE6/AIN0); also elsewhere on the board
row0: U1.25 (ICP1/PD4); also elsewhere on the board
row1: U1.26 (T1/PD6); also elsewhere on the board
row2: U1.28 (PB4); also elsewhere on the board
row3: U1.29 (PB5); also elsewhere on the board
row4: U1.30 (PB6); also elsewhere on the board

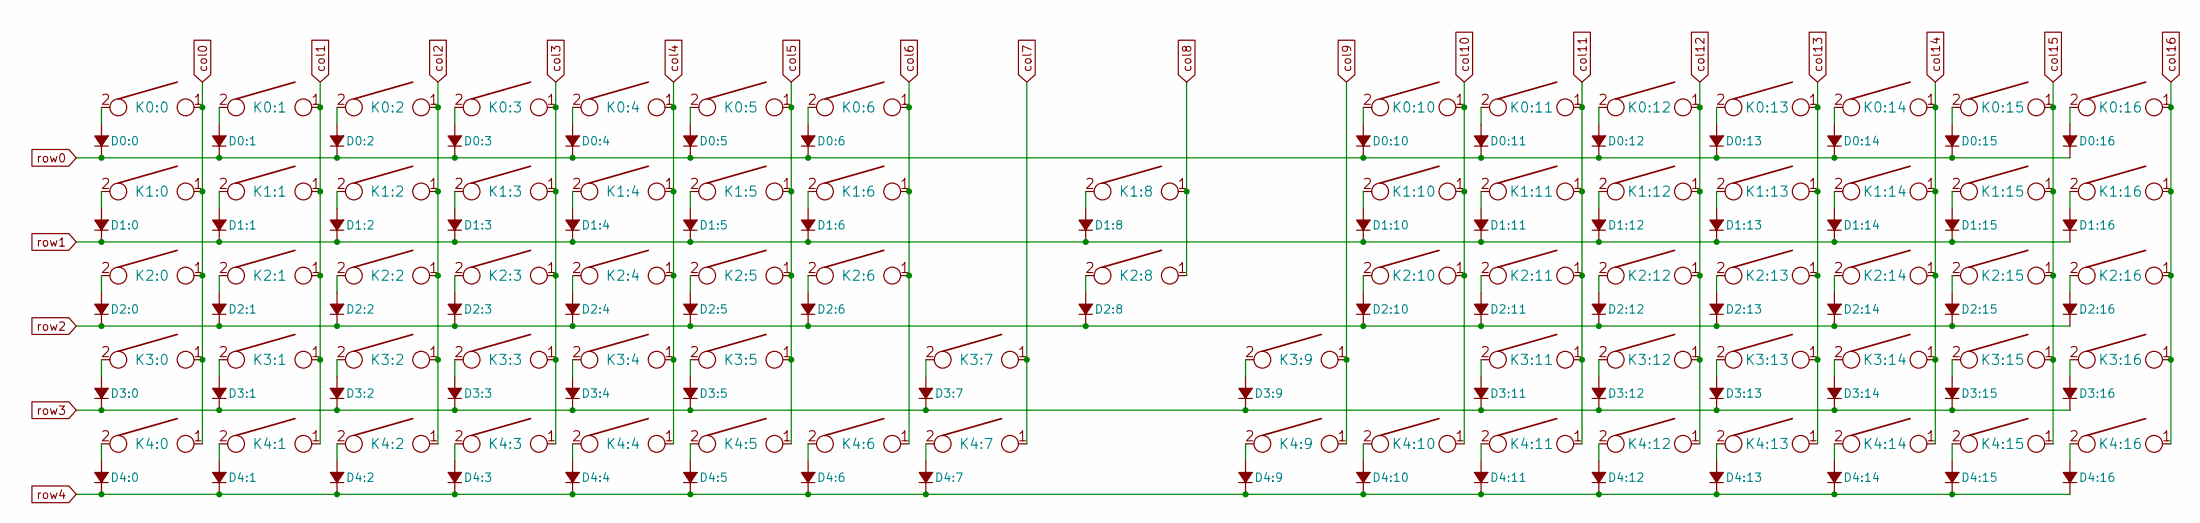
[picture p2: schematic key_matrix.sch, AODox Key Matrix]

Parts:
D0:0, D0:1, D0:2, D0:3, D0:4, D0:5, D0:6, D0:10, D0:11, D0:12, D0:13, D0:14, D0:15, D0:16, D1:0, D1:1, D1:2, D1:3, D1:4, D1:5, D1:6, D1:8, D1:10, D1:11, D1:12, D1:13, D1:14, D1:15, D1:16, D2:0, D2:1, D2:2, D2:3, D2:4, D2:5, D2:6, D2:8, D2:10, D2:11, D2:12, D2:13, D2:14, D2:15, D2:16, D3:0, D3:1, D3:2, D3:3, D3:4, D3:5, D3:7, D3:9, D3:11, D3:12, D3:13, D3:14, D3:15, D3:16, D4:0, D4:1, D4:2, D4:3, D4:4, D4:5, D4:6, D4:7, D4:9, D4:10, D4:11, D4:12, D4:13, D4:14, D4:15, D4:16: D_Small_ALT; D_SOD-323_HandSoldering
K0:0, K0:1, K0:2, K0:3, K0:4, K0:5, K0:6, K0:10, K0:11, K0:12, K0:13, K0:14, K0:15, K0:16, K1:0, K1:1, K1:2, K1:3, K1:4, K1:5, K1:6, K1:8, K1:10, K1:11, K1:12, K1:13, K1:14, K1:15, K1:16, K2:0, K2:1, K2:2, K2:3, K2:4, K2:5, K2:6, K2:8, K2:10, K2:11, K2:12, K2:13, K2:14, K2:15, K2:16, K3:0, K3:1, K3:2, K3:3, K3:4, K3:5, K3:7, K3:9, K3:11, K3:12, K3:13, K3:14, K3:15, K3:16, K4:0, K4:1, K4:2, K4:3, K4:4, K4:5, K4:6, K4:7, K4:9, K4:10, K4:11, K4:12, K4:13, K4:14, K4:15, K4:16: KEYSW; Kailh_socket

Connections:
unnamed: D0:0.2 (A), K0:0.2
unnamed: D0:1.2 (A), K0:1.2
unnamed: D0:2.2 (A), K0:2.2
unnamed: D0:3.2 (A), K0:3.2
unnamed: D0:4.2 (A), K0:4.2
unnamed: D0:5.2 (A), K0:5.2
unnamed: D0:6.2 (A), K0:6.2
unnamed: D0:10.2 (A), K0:10.2
unnamed: D0:11.2 (A), K0:11.2
unnamed: D0:12.2 (A), K0:12.2
unnamed: D0:13.2 (A), K0:13.2
unnamed: D0:14.2 (A), K0:14.2
unnamed: D0:15.2 (A), K0:15.2
unnamed: D0:16.2 (A), K0:16.2
unnamed: D1:0.2 (A), K1:0.2
unnamed: D1:1.2 (A), K1:1.2
unnamed: D1:2.2 (A), K1:2.2
unnamed: D1:3.2 (A), K1:3.2
unnamed: D1:4.2 (A), K1:4.2
unnamed: D1:5.2 (A), K1:5.2
unnamed: D1:6.2 (A), K1:6.2
unnamed: D1:8.2 (A), K1:8.2
unnamed: D1:10.2 (A), K1:10.2
unnamed: D1:11.2 (A), K1:11.2
unnamed: D1:12.2 (A), K1:12.2
unnamed: D1:13.2 (A), K1:13.2
unnamed: D1:14.2 (A), K1:14.2
unnamed: D1:15.2 (A), K1:15.2
unnamed: D1:16.2 (A), K1:16.2
unnamed: D2:0.2 (A), K2:0.2
unnamed: D2:1.2 (A), K2:1.2
unnamed: D2:2.2 (A), K2:2.2
unnamed: D2:3.2 (A), K2:3.2
unnamed: D2:4.2 (A), K2:4.2
unnamed: D2:5.2 (A), K2:5.2
unnamed: D2:6.2 (A), K2:6.2
unnamed: D2:8.2 (A), K2:8.2
unnamed: D2:10.2 (A), K2:10.2
unnamed: D2:11.2 (A), K2:11.2
unnamed: D2:12.2 (A), K2:12.2
unnamed: D2:13.2 (A), K2:13.2
unnamed: D2:14.2 (A), K2:14.2
unnamed: D2:15.2 (A), K2:15.2
unnamed: D2:16.2 (A), K2:16.2
unnamed: D3:0.2 (A), K3:0.2
unnamed: D3:1.2 (A), K3:1.2
unnamed: D3:2.2 (A), K3:2.2
unnamed: D3:3.2 (A), K3:3.2
unnamed: D3:4.2 (A), K3:4.2
unnamed: D3:5.2 (A), K3:5.2
unnamed: D3:7.2 (A), K3:7.2
unnamed: D3:9.2 (A), K3:9.2
unnamed: D3:11.2 (A), K3:11.2
unnamed: D3:12.2 (A), K3:12.2
unnamed: D3:13.2 (A), K3:13.2
unnamed: D3:14.2 (A), K3:14.2
unnamed: D3:15.2 (A), K3:15.2
unnamed: D3:16.2 (A), K3:16.2
unnamed: D4:0.2 (A), K4:0.2
unnamed: D4:1.2 (A), K4:1.2
unnamed: D4:2.2 (A), K4:2.2
unnamed: D4:3.2 (A), K4:3.2
unnamed: D4:4.2 (A), K4:4.2
unnamed: D4:5.2 (A), K4:5.2
unnamed: D4:6.2 (A), K4:6.2
unnamed: D4:7.2 (A), K4:7.2
unnamed: D4:9.2 (A), K4:9.2
unnamed: D4:10.2 (A), K4:10.2
unnamed: D4:11.2 (A), K4:11.2
unnamed: D4:12.2 (A), K4:12.2
unnamed: D4:13.2 (A), K4:13.2
unnamed: D4:14.2 (A), K4:14.2
unnamed: D4:15.2 (A), K4:15.2
unnamed: D4:16.2 (A), K4:16.2
col0: K0:0.1, K1:0.1, K2:0.1, K3:0.1, K4:0.1; also elsewhere on the board
col1: K0:1.1, K1:1.1, K2:1.1, K3:1.1, K4:1.1; also elsewhere on the board
col2: K0:2.1, K1:2.1, K2:2.1, K3:2.1, K4:2.1; also elsewhere on the board
col3: K0:3.1, K1:3.1, K2:3.1, K3:3.1, K4:3.1; also elsewhere on the board
col4: K0:4.1, K1:4.1, K2:4.1, K3:4.1, K4:4.1; also elsewhere on the board
col5: K0:5.1, K1:5.1, K2:5.1, K3:5.1, K4:5.1; also elsewhere on the board
col6: K0:6.1, K1:6.1, K2:6.1, K4:6.1; also elsewhere on the board
col7: K3:7.1, K4:7.1; also elsewhere on the board
col8: K1:8.1, K2:8.1; also elsewhere on the board
col9: K3:9.1, K4:9.1; also elsewhere on the board
col10: K0:10.1, K1:10.1, K2:10.1, K4:10.1; also elsewhere on the board
col11: K0:11.1, K1:11.1, K2:11.1, K3:11.1, K4:11.1; also elsewhere on the board
col12: K0:12.1, K1:12.1, K2:12.1, K3:12.1, K4:12.1; also elsewhere on the board
col13: K0:13.1, K1:13.1, K2:13.1, K3:13.1, K4:13.1; also elsewhere on the board
col14: K0:14.1, K1:14.1, K2:14.1, K3:14.1, K4:14.1; also elsewhere on the board
col15: K0:15.1, K1:15.1, K2:15.1, K3:15.1, K4:15.1; also elsewhere on the board
col16: K0:16.1, K1:16.1, K2:16.1, K3:16.1, K4:16.1; also elsewhere on the board
row0: D0:0.1 (K), D0:1.1 (K), D0:2.1 (K), D0:3.1 (K), D0:4.1 (K), D0:5.1 (K), D0:6.1 (K), D0:10.1 (K), D0:11.1 (K), D0:12.1 (K), D0:13.1 (K), D0:14.1 (K), D0:15.1 (K), D0:16.1 (K); also elsewhere on the board
row1: D1:0.1 (K), D1:1.1 (K), D1:2.1 (K), D1:3.1 (K), D1:4.1 (K), D1:5.1 (K), D1:6.1 (K), D1:8.1 (K), D1:10.1 (K), D1:11.1 (K), D1:12.1 (K), D1:13.1 (K), D1:14.1 (K), D1:15.1 (K), D1:16.1 (K); also elsewhere on the board
row2: D2:0.1 (K), D2:1.1 (K), D2:2.1 (K), D2:3.1 (K), D2:4.1 (K), D2:5.1 (K), D2:6.1 (K), D2:8.1 (K), D2:10.1 (K), D2:11.1 (K), D2:12.1 (K), D2:13.1 (K), D2:14.1 (K), D2:15.1 (K), D2:16.1 (K); also elsewhere on the board
row3: D3:0.1 (K), D3:1.1 (K), D3:2.1 (K), D3:3.1 (K), D3:4.1 (K), D3:5.1 (K), D3:7.1 (K), D3:9.1 (K), D3:11.1 (K), D3:12.1 (K), D3:13.1 (K), D3:14.1 (K), D3:15.1 (K), D3:16.1 (K); also elsewhere on the board
row4: D4:0.1 (K), D4:1.1 (K), D4:2.1 (K), D4:3.1 (K), D4:4.1 (K), D4:5.1 (K), D4:6.1 (K), D4:7.1 (K), D4:9.1 (K), D4:10.1 (K), D4:11.1 (K), D4:12.1 (K), D4:13.1 (K), D4:14.1 (K), D4:15.1 (K), D4:16.1 (K); also elsewhere on the board

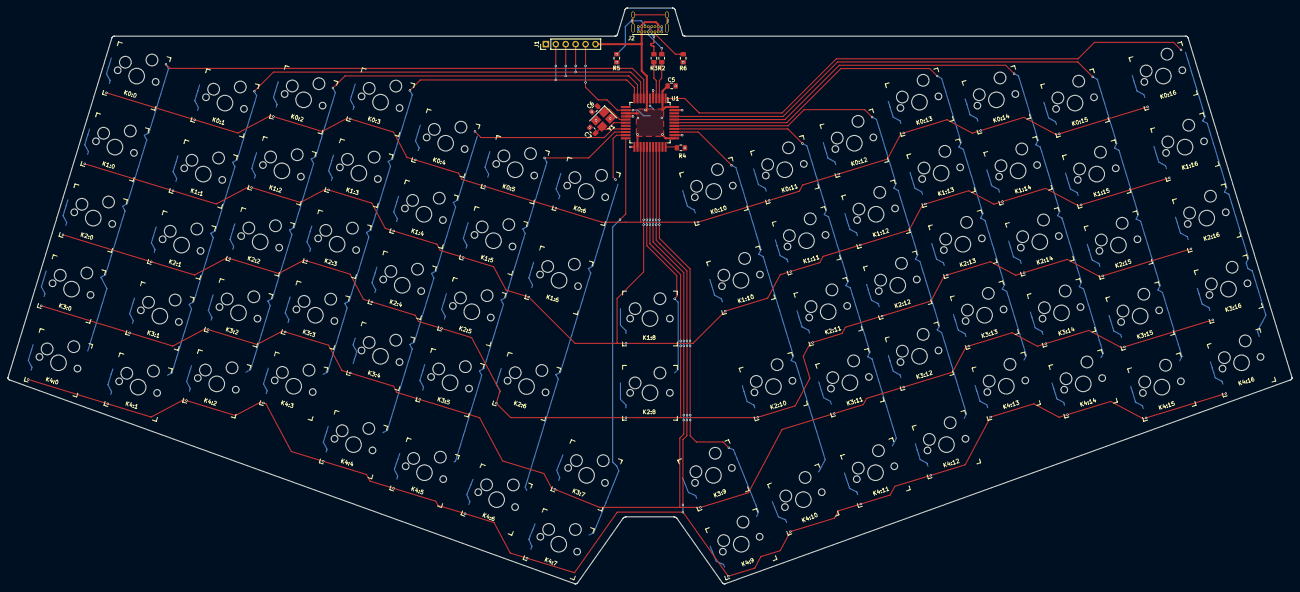
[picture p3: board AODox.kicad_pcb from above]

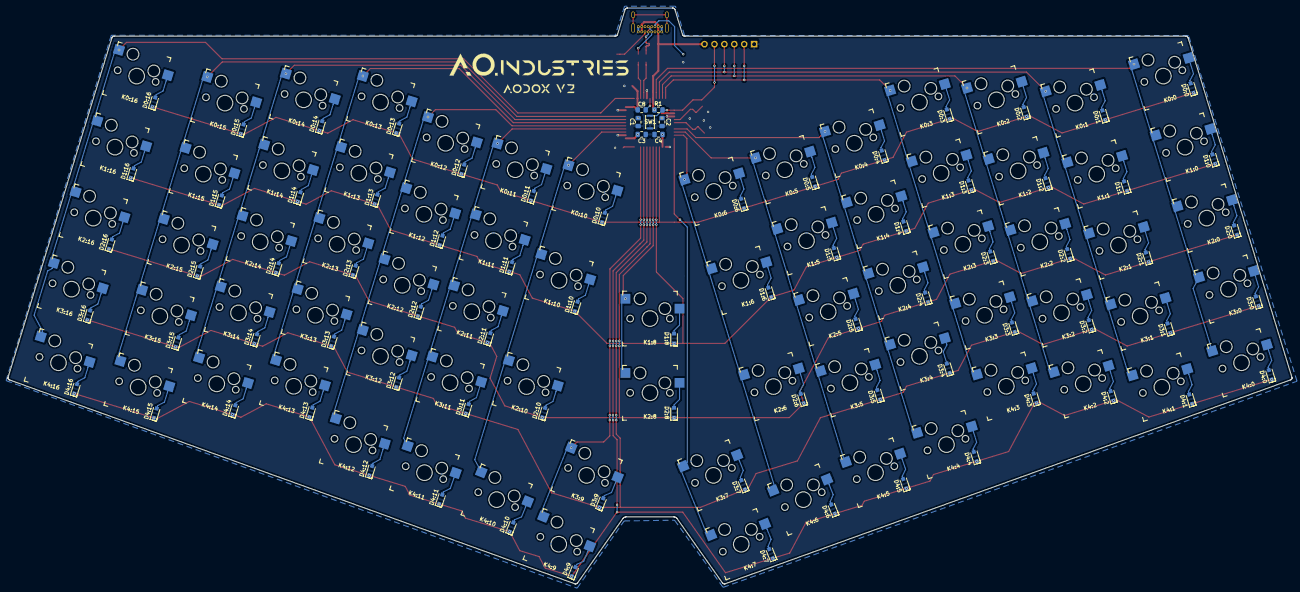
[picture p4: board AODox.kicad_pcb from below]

Board: 2 copper layers, 328.5 x 147.3 mm, 169 parts (82 on the bottom side), 109 nets.

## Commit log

2019-10-17 Take first cut at AODox layout and form factor
2019-10-21 Finish case v1
2019-10-21 Add basic MCU configuration schematic
2019-10-22 Add key matrix schematic
2019-10-22 Update schematic annotations
2019-10-22 Assign footprints to schematic symbols
2019-10-23 Create print layer for printing out and testing
2019-10-24 Update case to v2
    Remove 1.5u keys in center and moves halves closer together. Change
    interkey spacing from 0.55mm to 0.5mm. Increase base tilt from 16° to 17°.
2019-10-25 Complete v2 case design
2019-10-26 Rough out PCB layout
2019-11-21 [PCB] Route out traces on board
2019-12-18 Update case design based on laser cutter testing
2021-12-12 Tweak directory capitalization
    Seemed to be related to an issue that prevented the firmware from building. Seems dumb, but it really seems like that's the case.
2022-06-16 Start tracking new kicad files
2022-12-25 =all: Scrub PII + re-add files
    Everything before here is just commit messages, for historical reference.
    Scrubbed all PII.
    [AODox-B_Cu.gbl, AODox-B_Mask.gbs, AODox-B_Paste.gbp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]
